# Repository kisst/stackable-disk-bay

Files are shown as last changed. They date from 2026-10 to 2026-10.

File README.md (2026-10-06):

# Stackable disk bay



A 3D-printable bay and toolless caddy for 3.5" hard drives, and for 2.5"
drives through an adapter in the same caddy. Bays are identical
and sit on top of and beside each other, located by hex bumps that drop into
the neighbour's honeycomb, with no connector parts. The drive drops into the
caddy without screws; the caddy slides into the bay and clicks home. Every
part prints flat, no supports.

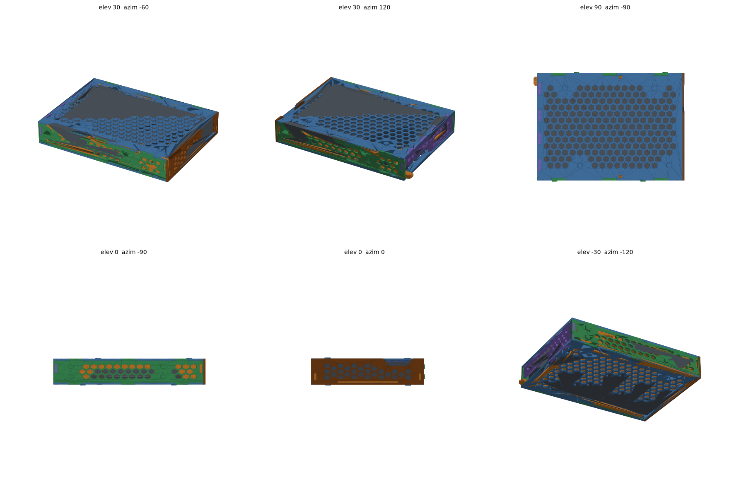
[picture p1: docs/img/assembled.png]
One assembled unit from six directions, one colour per printed part


**Status: first test print done; its findings are in this revision, which
is verified by the geometry checks but not yet reprinted.** The drive-in-caddy
fit is still untested. See [docs/design.md](docs/design.md) for the spec and
the print results.

## Parts

| Part | File | Per bay | Print |
| --- | --- | --- | --- |
| Caddy tray | `scad/caddy_tray.scad` | 1 | flat on its floor |
| Caddy bezel | `scad/bezel.scad` | 1 | flat, front face down |
| Plate, top and bottom | `scad/plate.scad` | 1 + 1 | flat, bumps up; top has six slots, bottom two |
| Wall (left and right) | `scad/wall.scad` | 2 | flat, bumps up |
| Rear panel | `scad/rear.scad` | 1 | flat |
| Pin coupon | `scad/coupon.scad` | optional | flat |

Accessories:

| Part | File | Use | Print |
| --- | --- | --- | --- |
| 2.5" adapter | `scad/adapter25.scad` | one per 2.5" drive, in a normal caddy | flat on its base |
| Foot | `scad/foot.scad` | four under each bottom bay | flat, pins up |
| Width joiner, 1 and 0.5 | `scad/joiner.scad`, `kind="w1"` / `"w05"` | between stacked bays | flat |
| Height joiner, 3, 1 and 0.5 | `scad/joiner.scad`, `kind="h3"` / `"h1"` / `"h05"` | between bays side by side | flat |

Print the coupon first: a 34 mm slice of the caddy with one fixed pin and one
finger, to check pin diameter and finger stiffness on a real drive.

Views (not prints), all in `out/` after a render:

| Image | Shows |
| --- | --- |
| `assembled.png` | one assembled unit, every printed part plus the drive |
| `testfit.png`, `testfit_open.png` | one unit with the drive and SATA plugs, one colour per part; the second with the top plate lifted off |
| `assembly_steps.png` | assembly drawing: walls on the rear panel's side tabs, lifted above the bottom plate, top plate above |
| `join_stack.png`, `join_side.png`, `join_detail*.png` | how bays join, exploded and close up |
| `assembly_parts.png` | the 2 × 2 combo, one colour per part class |
| `assembly_units.png` | the 2 × 2 combo, one colour per bay |

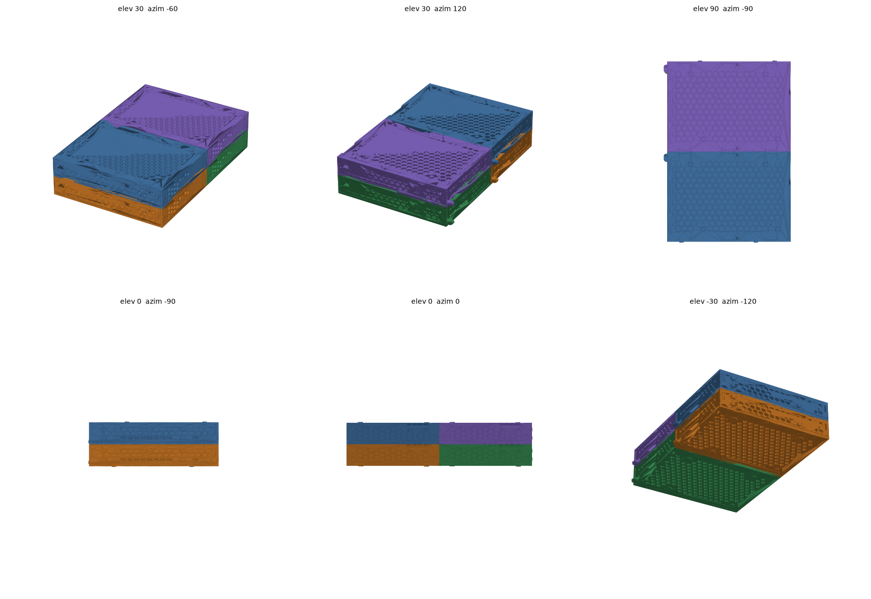
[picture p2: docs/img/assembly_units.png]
A 2 × 2 block of loaded bays, one colour per bay


The walls and rear panel carry a low groove that must line up round the
bay. The plates need no mark: the top has six slots, the bottom two, and
the rear-panel slots sit at the rear edge.
`scad/hdd.scad` is the reference drive and `scad/sata_plugs.scad` the mated
cable plugs used for the rear cutout check.

## Assembly

Step by step with pictures: [docs/assembly.md](docs/assembly.md).

## How it works

- **Drive in caddy.** Two fixed pins on one wall, two pins on 45° cantilever
  fingers on the other. Tilt the drive onto the fixed pins, press the other
  edge down, the fingers flex out and the pins snap into the drive's side
  holes. The fingers are diagonal so their slots print without support; the
  recessed tip gives a fingernail purchase to release.
- **Caddy assembly.** The bezel presses onto tabs on the tray's walls and
  floor, a friction fit; glue is optional.
- **Caddy in bay.** Slide it in until the bezel seats on the bay's front face.
  The top edge of each caddy wall is a leaf spring with a ramped bump. The
  bumps ride under the top plate's solid rim and drop into two slots when
  the caddy seats. The springs stay preloaded, holding the caddy down and the
  bezel tight against the bay. There is no honeycomb on the bump's track, so
  there are no false clicks. To remove, pull by the notch cut into the
  bezel's top edge; there is no handle, so the bezel prints flat. Or push it
  out from behind: the tray's rear corner reaches through the rear panel's
  open SATA corner as a push tab.
- **Bay assembly.** Walls slid onto the rear panel's side tabs; that U
  lowered into the bottom plate; top plate on. Every tab fits its slot
  exactly. The panel's open corner clears the SATA plugs. Glue is
  optional. A set of checks proves the insertion path.
- **Bay to bay.** No extra parts. Every bump stands on its part's honeycomb
  lattice, offset so that the same part turned for the opposite face presents
  an open cell where each bump arrives: plates turned over for stacking,
  walls turned end for end for side by side. Set a bay on top or beside,
  facing the same way, done. Bumps locate, they do not lock: glue them if a
  block must lift as one.
- **Airflow.** Honeycomb through plates, walls, caddy floor and bezel, inside
  solid rims that carry the load.

## Tooling

Needs Docker and a stock `python3` (standard library only). OpenSCAD
(`openscad/openscad:2021.01`) and the preview renderer run in containers.

```sh
scripts/render.sh          # STL + PNG for every part and view -> out/
scripts/assemblies.sh      # coloured 3MF assemblies -> out/assemblies/
scripts/check.sh           # all interference checks; all must PASS
scripts/check.sh quick     # single unit and neighbours only
scripts/check.sh array     # loaded 2x2 combo only (slow, CGAL)
scripts/check.sh acc       # accessories: 2.5" adapter, feet, joiners
scripts/check.sh only a b  # the named checks only
scripts/thin.sh            # no part has material under 0.8 mm (two perimeters)
AXES=z scripts/thin.sh wall  # one part along one axis
scripts/vent.sh            # caddy floor and bay plate honeycombs line up
```

`scripts/check.sh` intersects pairs of bodies and asserts the result is empty
(a face-to-face touch passes, a volume fails), or, for the hold checks, that a
displaced part hits material: tabs shifted in their slots, neighbours shifted
along the bay into the bumps. `scripts/thin.sh` slices every part in its print orientation,
opens each slice by 0.4 mm and fails on whatever the opening removed, unless
it is only the tail of a slice grazing a sharp corner.

GitHub Actions runs `check.sh`, `thin.sh` and `vent.sh` on every push and
pull request, and builds the printable STLs and the 3MF assemblies as
downloadable artifacts. Pushing a `v*` tag publishes both as a GitHub Release
once every check passes. The 3MFs carry one coloured object per part:

| 3MF | Contents |
| --- | --- |
| `assembled_hdd35.3mf` | bay, caddy and 3.5" drive, seated |
| `assembled_hdd25.3mf` | bay, caddy, 2.5" adapter and 2.5" drive, seated |
| `bay.3mf` | the bay alone: plates, walls, rear panel |
| `caddy_hdd35.3mf` | tray, bezel and 3.5" drive |
| `caddy_hdd25.3mf` | tray, bezel, 2.5" adapter and 2.5" drive |

## Layout

```text
scad/       params.scad lib.scad hdd.scad hdd25.scad sata_plugs.scad              shared model
            caddy.scad bay.scad accessories.scad
            caddy_tray.scad bezel.scad plate.scad wall.scad rear.scad coupon.scad  printable parts
            adapter25.scad foot.scad joiner.scad
            testfit.scad assembly.scad joining.scad steps.scad accessory_views.scad   views
            checks.scad thin.scad vent.scad                                        verification
scripts/    render.sh assemblies.sh check.sh thin.sh vent.sh
            preview.py color_mesh.py stl_components.py stl_bbox.py
docs/       design.md adr/ img/
out/        build output (ignored)
```

## License

[MIT](LICENSE)

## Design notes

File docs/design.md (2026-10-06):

# Design

## Goals

1. Hold a 3.5" drive (SFF-8301) without screws or tools, and a 2.5" drive
   (SFF-8201) through an adapter that takes the 3.5" drive's place in the
   same caddy, with no change to the caddy or bay.
2. Bays stack vertically and join side by side, with a positive clip-in
   connection; every bay is the same part.
3. Print on a common 220 × 220 mm bed, every part flat, no supports.
4. Keep air moving over and under the drive; stay rigid enough that a stack
   of loaded bays does not rack.

Non-goals for now: backplanes, fans, hot-swap electronics, and any metal
hardware.

## Coordinate frame

Shared by every part so the assembly and the checks need no offsets.

- **x** rear → front. The drive's connector face is at x = 0, the bezel at the
  front.
- **y** width, centred on 0. −y is the fixed-pin wall; +y is the finger
  wall and the side the drive's SATA connector is on (on the left, seen
  from behind with the label up).
- **z** 0 is the caddy floor's underside, which is also the bay floor's top.

## Drive envelope used

| | mm | source |
| --- | --- | --- |
| width | 101.6 | SFF-8301 A3 |
| length | 147.0 max | A4 |
| height | 26.1 max | A1 |
| side holes above bottom | 6.35 | A8 |
| side holes from connector face | 28.5 and 130.1 | A6, A6 + A7 |
| side hole thread | 6-32 UNC, minor ≈ 2.8 | |

The pins are 2.6 mm so they enter the thread's minor diameter with 0.1 mm a
side. Shorter or lower drives (20.2 mm) fit; only the hole positions matter.

## Caddy

A tray: honeycomb floor in a 6 mm solid frame, two 2.4 mm walls 25 mm tall
with honeycomb on the bay wall's lattice, and a front bezel the size of the
bay's face with a finger notch.

- **Fixed pins** on the −y wall at the two hole positions, conical tips.
- **Finger pins** on the +y wall sit at the lower ends of two cantilever
  fingers that run at 45° from the wall's top rim down to the pin, 6 mm wide
  in the wall's plane, 1.6 mm thick (the outer face is recessed 0.8 mm), cut
  free by a 1.2 mm slot. The angle is for printing: every slot face is a 45°
  overhang, so the tray prints flat with no support, where a horizontal
  finger floats over its lower slot on its first layer. The beam's lowest
  corner is cut flat 1.6 mm wide, so its first layer is a bead four lines
  wide rather than a point. The fingers are about 18 mm long; clearing the
  2.1 mm pin takes about 2.3 mm of deflection, which is about 1.5 % strain
  at the root: fine in PETG, acceptable in PLA. The recessed outer face
  gives a fingernail the purchase to release, but a test fit showed that
  is not enough once the pins are in a drive's holes.
- **Service holes**: one honeycomb cell on the wall lattice beside each
  finger's tip, at pin height (the lattice row at 8.25 mm), the first cell
  past the slot's tip corner: x 137.55 for the front finger, 20.55 for the
  rear. It overlaps the slot's end, so hole and slot are one opening, and
  a small screwdriver gets at the tip to pry the pin out of the drive. The
  cell's slanted edges run on to the slot's edges, so no step of wall is
  left where the two meet, and the wedge of wall above and below each
  meeting point is cut flat where it is 1 mm wide, so its first layers are
  not thinner than two perimeters. It
  clears the beam by 0.2 mm (front) and 0.7 mm (rear); `service_holes()`
  asserts that. The 3 mm rim above a finger
  is measured from the slot's highest point, the corner of its ring at the
  root, which sits 3 mm above the beam's centreline.
- **Spring lock** for retention in the bay, on the top edge of both walls.
  A 54 mm slit under the rim (x 56 to 110, between the +y wall's finger
  slots) frees a 2 mm beam anchored at both ends, under a 1.5 mm hump that
  rises from the rim on 15° ramps with 6 mm radii. A bump in the beam's
  middle rides on the top plate's underside. It has a 30° lead-in ramp facing
  the rear, a 45° holding ramp facing the front and a 1.2 mm crest, with
  1.5 mm fillets at its foot and a 1 mm radius on the crest, and reaches
  1.0 mm into the plate when relaxed. Its track
  lies under the plate's solid rim, outside the honeycomb, so it has nothing
  to drop into until it reaches its slot at the seated position. The slot's
  front edge meets the holding ramp with 0.4 mm of deflection left, so the
  spring keeps pushing the caddy down and the bezel onto the bay. Anchored at
  both ends, the beam's underside prints as a bridge; the bump stands upright
  on the edge. The beam rate is about 4 N/mm in PETG and 7 N/mm in PLA per
  side, at 0.8 % strain when pressed flat. A finger in the bezel's notch
  overcomes the 45° ramps.
- **Push tab** at the rear +y corner, so the caddy can be pushed out from
  behind without loading the bezel joint. The tray's floor corner runs back
  through the rear panel's open SATA corner and ends 5 mm behind the bay's
  rear face. It is a floor-level plate 10 mm wide, which passes under the
  SATA plugs (their housings start 2.4 mm up), plus a 6 mm rib in line with
  the side wall that sweeps up into the wall's rear edge on an 8 mm fillet.
  Both rear corners are rounded in plan and the rib's top edge is rounded.
  It prints on the bed with the tray.
- **Wall vents**: the caddy walls reach 27 mm and would otherwise cover
  the bay's side honeycomb, so they carry the same 6 mm lattice, phased to
  the bay wall's, with solid zones round fingers, pins and the bezel tabs.
  The zone round a finger is the bounding box of its slot ring and recess
  plus the 1.5 mm web margin, so no cell comes near a slot's tip corner.
- **Bezel** is a flat 2 mm plate the size of the bay's front face. It seats
  on the front edge of the plates and walls and carries a honeycomb intake
  over the drive's front. There is no handle. A drawer-style notch in the
  top edge near the +y corner, 36 mm wide, 14 mm deep, with rounded corners,
  gives a place to pull by; the honeycomb stays solid round it. It joins the
  tray by three tabs, one on each wall end and one on the floor, through
  slots in the plate. It is a separate print, front face down, because its
  lower edge reaches below the tray's floor.
- **Bezel lip**: a 2 mm lip on the bezel's back face at the top, 1.4 mm
  thick, 3.5 lattice pitches (27.3 mm) long, from y −26.1 to 1.2: the
  middle, where the top plate sags most, on the fixed-pin side and clear of
  the finger notch. When the caddy is seated it sits under the top plate's
  solid front rim, its top 0.2 mm under the plate's underside, and props the
  plate up. A 0.5 mm chamfer on its rear top edge lets a sagging plate ride
  up onto it. It reaches 1.5 mm over the drive's front edge, 0.3 mm above
  a 26.1 mm drive. The drive goes in fixed-pin edge first and sits lowest
  there, and passes under the lip by flexing the bezel as the other edge
  is pressed down. Checks: `bezel_lip_holds` (the plate let down 0.4 mm
  hits it) and `path_bezel_lip` (3 mm from seated, the lip is already
  under the rim and clears the bay).
- **Wall front posts**: near its edges the top plate is propped by the
  caddy walls instead. Over their last 8 mm at the bezel end both walls
  rise from 27 mm to 29.8 mm, 0.2 mm under the plate's underside, with a
  45° ramp behind that lifts a sagging plate as the caddy goes in. The
  0.2 mm gap, like the lip's, keeps them from binding in a bay printed a
  little short. Check: `posts_hold`.

Clearances: 0.3 mm a side drive-to-caddy, 0.4 mm a side caddy-to-bay.

## Bay

Five flat parts, all 2.4 mm: two identical plates, two identical walls and a
rear panel. Inner section 107.8 × 30.0; the bay runs from 5 mm behind the
drive's connector face to the bezel, 152.5 mm. The bezel stops the caddy.

- **Plate**: honeycomb inside a 6 mm rim, six through-slots for the wall
  tabs, rear-panel slots (four in the top plate, two in the bottom), two
  lock slots for the caddy's spring bumps in the top plate only, four hex
  bumps on one face. The bottom plate is turned over so its bumps face
  down.
- **Wall**: honeycomb inside a 4 mm rim, three 14 mm tabs on each long edge,
  four hex bumps on the outer face on the lattice's rows +1 and −1, and a
  slot for the rear panel's side tab, sized to the tab. The right wall is
  the same part turned end for end, so the slot is cut at both ends; the
  front one is unused, behind the bezel.
- **Rear panel**: an L. The lower +y corner is open from the bottom edge
  and the side edge up to 12.5 mm, just under the wall tab, for the SATA
  power and data plugs; a closed window there would leave slivers weaker
  than no material. Exhaust honeycomb over the rest, four tabs along the
  top edge into the top plate, two on the −y half of the bottom edge into
  the bottom plate, and one tab on each side edge, 13 to 25 mm up, through
  a slot in each wall. Each plate carries only the slots the
  panel's tabs use; the bottom plate's are mirrored, as it is turned over.
  The panel sits 1.2 mm behind the drive's connector face.
- **Front**: with the caddy in, its tray sits inside the bay at 0.4 mm a
  side, which keeps the walls from spreading; the bezel plate only seats on
  the front edge. The rear panel squares the back.
- **Orientation marks**: a 1 mm groove, 0.6 mm deep, runs along the outside
  of both walls and the rear panel 1.8 mm above the inner floor. When the
  three grooves line up in one low line round the bay, every part is the
  right way up; a wall or panel put in upside down shows its groove near the
  top. The plates need no mark. Their rear-panel slots sit at the rear
  edge, which shows which way round a plate goes, and the bumps face out.
  Top and bottom are separate prints told apart by their slots: the top
  plate has six (four for the rear panel, two for the caddy lock), the
  bottom plate two (the rear panel's, mirrored because it is turned
  over). The wall has a rear-panel slot at both ends so one part serves
  both sides without a mirror image; the unused front slot sits behind the
  bezel.
- **Fit**: wall tabs are 0.15 mm a side smaller than their plate slots. The
  rear panel's tabs are 0.08 mm a side in every slot, a friction fit. Press
  together; a drop of glue at the tabs makes it permanent.

### Joining bays

No extra parts in either direction. Every bump is 5.6 mm across flats,
1.4 mm tall, and stands on its part's own 6 mm honeycomb lattice, placed so
that when the identical part is turned for the opposite face, each bump of
one bay arrives in an open cell of the neighbour's part.

**Stacking.** The plate bumps sit at columns −6 and +6 of row +6 and
columns −4 and +8 of row −6. Turning the plate over for the bottom mirrors
y, so each bump lands two cells from any pad: an open cell. Stack pitch is
the bay height, 34.8 mm. The offset depends on both bays facing the same
way, front to front.

**Side by side.** The walls share the 6 mm lattice (three rows fit in the
30 mm height; the bumps use rows +1 and −1 and leave row 0 for venting).
The right wall is the left wall turned end for end, which maps column i to
−i−1 on those rows. Bumps at columns −8 and +4 land at +7 and −5, three
cells from any pad. Bays touch; lateral pitch is the bay width, 112.6 mm,
and neighbouring bezels meet edge to edge.

Both joints locate and square the array and stop sliding; neither carries
a bay if its neighbour is lifted. Glue the bumps for that.

To join, set the next bay on top, or bring it in from the right, facing the
same way; its cells drop over the bumps and the faces
touch. The array grows as high and as wide as you like.

### Assembling a bay

Insertion order and directions; [assembly.md](assembly.md) has the same steps
with pictures:

1. **Walls onto the rear panel.** Panel groove low, SATA notch at the
   bottom on the +y side, the drive's connector side. Slide each wall
   sideways onto the panel's side tab, wall groove low on the outside;
   either end of a wall may face the rear. Panel and walls now stand as a
   U.
2. **Into the bottom plate.** The plate with two slots, bumps down, slots
   at the rear. Lower the U onto it: the walls' three bottom tabs and the
   panel's two bottom tabs all drop into their slots together.
3. **Top plate on.** The one with six slots, bumps up, the row of four at
   the rear; it drops over the walls' top tabs and the panel's four top
   tabs. Glue the tabs if the bay will be moved about.

Because the walls go onto the panel before either meets a plate, every
slot only ever sees one direction of travel and fits its tab exactly; the
v0.1.0 order, panel in the plate first and walls slid on lifted, needed a
side slot 2.4 mm too tall. `scripts/check.sh` proves the path: a wall
approaching the panel sideways, the U half-way down into the bottom plate,
and the top plate half-way down all clear the parts already placed. A
panel shifted 1 mm along the bay hits the walls alone, so the side tabs
really sit in the slots.

### Venting

Honeycomb (6 mm cells, 1.8 mm web) through both plates, both walls and the
rear panel, stopping 6 mm from the plate edges and 4 mm from the wall edges.
The walls fit three rows; the bumps take rows +1 and −1 and row 0 vents.
Cells are skipped within 1.5 mm of a bump, a tab slot, a lock slot or the
SATA cutout. Air enters through the
bezel, passes over and under the drive, and leaves through the rear panel.

The caddy floor and the bay's bottom plate are two honeycombs in series
under the drive. They use the same 6 mm lattice and the caddy's grid is
phased to the plate's centre, so the cells coincide when the caddy is in.
`scripts/vent.sh` sections both at mid-thickness and intersects them:

| | open area | of drive footprint |
| --- | --- | --- |
| caddy floor alone | 6955 mm² | 46.6 % |
| bay bottom plate alone | 6485 mm² | 43.4 % |
| straight through both | 6105 mm² | 40.9 % |

The remaining loss is the plate's solid pads around bumps and tab slots,
which the floor cannot see past. The script fails if
the through-open area drops under 85 % of the smaller layer, which is what
a drift between the two lattices would look like. The open floor lets air
reach the drive's underside, where the PCB and spindle motor are. The
bezel uses the same 6 mm cells as every other part.

## Accessories

### 2.5" adapter

The adapter takes the place of a 3.5" drive in an ordinary caddy, so the
caddy, bay and rear panel are unchanged. It is 101.6 mm wide with holes for
the caddy's four pins: teardrop holes through a strip along the +y wall for
the finger pins, and through an outer rail on the −y side for the fixed
pins.

SATA puts the connector at the same place on both sizes: SFF-8323 (3.5")
and SFF-8223 (2.5") both give 13.43 mm from the drive's edge to the blade
and 3.5 mm up from the bottom. So the 2.5" drive sits in the adapter's +y
rear corner, on the caddy floor with its connector face at x = 0. Its
connector then lands where a 3.5" drive's would, moved inboard only by the
2.2 mm strip that carries the finger pins plus 0.2 mm clearance. The plugs
still pass through the rear panel's open corner.

The 2.5" drive hangs on three pins into its M3 side holes (SFF-8201: 3 mm
up, 14.0 and 90.6 mm from the connector end): two on the −y rail, one on
the +y strip near its free end. Tilt the drive onto the rail's pins and
press the other side down; the strip flexes out and its pin snaps in. In
the caddy the strip is backed by the caddy wall, so the drive cannot come
out; at the strip's pin, 14 mm from the rear, that wall is solid, ahead of
the first finger's slot. The base beside and in front of the drive
carries honeycomb on the caddy floor's lattice. Drives 5 to 15 mm tall fit.

### Feet

A hexagonal foot, 24 mm across flats, lifts the bottom bay 12 mm for air
under it. Three hex pins, the bumps' shape and 2.0 mm tall, drop into three
neighbouring open cells of the bottom plate, two in one row and one in the
row above between them. The pins stay inside the 2.4 mm plate, clear of
the caddy floor. Four feet go near the corners, at the cell clusters in
`foot_cells`; any cluster of three open cells works.

### Joiner plates

A joiner is sandwiched between two bays: bay, joiner, bay. It is 2.8 mm
thick, twice a bump's height, so each bay's bumps drop 1.4 mm into holes
from its own side. Width joiners go between stacked bays and come one or
half a bay wide. Height joiners go between bays side by side and come
three, one or half a bay high. All are as long as the bay.

Pieces lock edge to edge with dovetails, two tabs and two sockets per
edge. The sockets sit at the mirror positions of the tabs, so a piece
turned round still mates. Half pieces lock on one edge only, so they end a
run flush. 0.5 + 1 + 0.5 lays a joint two bays long whose seams fall at
mid-bay, tying the two bays together like bricks; 0.5 + 0.5 covers a single
bay.

The plates are honeycomb all over, on the lattice of the bay half each
zone lies against, so every bump lands in a cell and air passes straight
through. The lattice is symmetric about a bay's centre line, so a half
piece cut for the half on one side of it serves the other half turned
round. A full piece straddles the seam between two bays, as in a run; a
single bay takes two half pieces. The three-high piece runs from one bay's
centre line to the one three bays up, so 0.5 + 3 + 0.5 joins four rows.
Width zones fit seven rows of cells. Height zones, 17.4 mm high, fit only
the bump row, with cells skipped next to the dovetails.

Columns of a block with width joiners touch directly, and so do the rows
of a block with height joiners. Use one joiner direction per block: either
direction already ties the block together. Stacked pitch with a joiner is
37.6 mm, side-by-side pitch 115.4 mm.

## Print orientation

Everything flat, nothing needs support.

| Part | Footprint | Notes |
| --- | --- | --- |
| Caddy tray | 107 × 159.5 mm, 31 mm tall | pins are small horizontal protrusions; finger slots are 45°; the spring slits bridge 54 mm |
| Caddy bezel | 112.6 × 34.8 mm, 4 mm tall | front face down; a flat plate with the 2 mm lip standing up |
| Plate, top and bottom | 112.6 × 152.5 mm | bumps up; slots differ |
| Wall | 152.5 × 34.8 mm | bumps up |
| Rear panel | 112.6 × 34.8 mm | |
| Coupon | 34 × 107 mm | |
| 2.5" adapter | 143.5 × 101.6 mm, 12 mm tall | caddy-pin holes are teardrops; the drive pins are small horizontal protrusions |
| Foot | 24 mm across flats, 14 mm tall | pins up |
| Width joiner | 152.5 × 112.6 (1) or 56.3 mm (0.5), 2.8 mm | |
| Height joiner | 152.5 × 104.4 (3), 34.8 (1) or 17.4 mm (0.5), 2.8 mm | |

## Verification

`scripts/check.sh` proves, by boolean intersection in OpenSCAD:

- the walls' and rear panel's tabs sit in their slots without overlap, and a
  wall or panel shifted 1 mm hits plate or wall material (the tabs engage);
- the rear panel clears the drive and its connectors, and the bezel seats on
  the bay's front face (a bay pushed 1 mm forward hits it);
- the caddy with a drive sits inside the bay touching only where the bezel
  seats and where the preloaded lock bumps bear on their slots' front edges;
  the drive touches the caddy only on the floor (pins are inside the holes);
- the push tab clears the mated SATA plugs, and every part of the tray that
  ends up behind the rear panel passes through the panel's open corner on
  the way in;
- the seated caddy pulled 1 mm out hits the lock slots; while sliding in,
  with the bumps pressed flat, it clears the bay; the bumps' track from the
  bay's front edge to the slot is solid plate;
- stacked and side-by-side neighbours touch only on their faces, and a
  neighbour shifted 1 mm along the bay hits the bumps (they sit in open
  cells of the neighbour's part);
- in a 2 × 2 array with a caddy and drive in every bay, no loaded unit
  overlaps any other, including the diagonals, and a loaded caddy never
  reaches a neighbour's bumps;
- accessories (`check.sh acc`): the 2.5" adapter sits in the caddy and the
  2.5" drive in the adapter, its plugs pass the rear panel, and each is held
  by the pins; the feet sit in the bottom plate's cells and hold; width and
  height joiners sit between their bays, a 0.5 + 1 + 0.5 run fits both
  ways, its dovetails lock, and a joiner shifted 1 mm hits the bumps.

`scripts/thin.sh` proves that no printed part has material thinner than two
perimeters (0.8 mm). It slices each part in its print orientation every
0.4 mm along z and every 2 mm along x and y, opens each slice by 0.4 mm
(straight-edged erosion, round dilation, so a tapering wedge is caught as
well as a parallel sliver) and exports what the opening removed. The round
dilation also nibbles every convex corner by 0.4 mm: a right-angle nib is
0.034 mm², two of them merged across a hair-thin slit about 0.07 mm², so
anything under 0.1 mm² is dropped; a real thin wedge, such as one over a
finger root, is 0.3 mm² or more. What remains is classified by how
it joins the thick material: at two or more places it is a neck or a roof
and fails; over more than 1.5 mm it is a fin and fails; at none it is an
island, which fails in the z pass (a first layer in the air, or a pillar)
and passes in the x and y passes, where an island is the apex of a corner
pointing along the slice normal and anything real there is a neck or fin
in another pass; a single short contact is the tail a slice leaves when it
grazes a sharp corner, and passes. Pins are left off the tray for this
check: a horizontal cylinder sliced near its tangent is
always thin.

The reference drives (`scad/hdd.scad`, `scad/hdd25.scad`) carry a SATA
device plug to the SATA-IO layout, horizontal L-shaped tongue at the bottom
of the connector face, 7-contact signal segment nearest the drive's edge,
15-contact power segment inboard, 1.27 mm pitch, in a pocket. A separate
model, `scad/sata_plugs.scad`, holds the mated data and power cable plugs,
and a check proves they pass through the rear panel's cutout. The
connector's position is from SFF-8323: the blade starts 13.43 mm from the
drive's edge (dimension A13) and sits 3.5 mm up from the bottom (A7).
SFF-8223 gives the same two numbers for 2.5" drives. The edge is the +y one:
seen from behind with the label up, the connector is at the left, data plug
outermost. A real drive shows this; the first model had it mirrored ([ADR
0010](adr/0010-sata-connector-on-the-plus-y-side.md)). Segment lengths and
pocket depth are nominal, so the cutout should still be confirmed against a
real drive before printing many rear panels.

## First print

The first test print found:

1. The rear panel was loose in the walls: the side tab sat in a slot 2.4 mm
   taller than itself, slack the old lifted-wall assembly needed. Now the
   walls go onto the panel first and the slot fits the tab exactly.
2. The caddy never clicked into the bay: the detent bumps on the side finger
   barely reached past the slide clearance and the finger yielded inward.
   Now a leaf spring on each wall's top edge locks into the top plate.
3. The bezel tab slots, the long floor slot above all, were too loose to
   hold without glue. Now 0.08 mm a side across the wall tabs and 0.05 mm
   across the floor tab.
4. The rear panel's plate slots were too loose. Now 0.08 mm a side.

See [ADR 0005](adr/0005-top-edge-spring-lock-grooved-rear-panel.md).

After the print, the bezel's handle was replaced by a finger notch, so it
prints as a flat plate; see
[ADR 0006](adr/0006-bezel-finger-notch-instead-of-handle.md).

## What the next print has to answer

1. Whether the tighter friction fits (bezel tabs, rear panel) press home by
   hand and hold without glue.
2. Spring lock: click, hold and release force, and whether the 54 mm slit
   bridges cleanly in the chosen filament.
3. Whether the bezel notch gives enough grip to pull the caddy out against
   the spring lock.
4. Drive in caddy, still untested: finger stiffness at 1.5 % strain, and
   whether 2.6 mm pins seat in the tapped holes of the drives on hand.
5. Fit of the 5.6 mm bumps in the 6.0 mm cells; one parameter.
6. Rigidity of a loaded 2 × 2 block located by bumps alone; if it racks,
   glue the bumps.
7. Whether a drive goes into a caddy with its bezel on, under the bezel's
   lip, by flexing the bezel, and whether the lip holds the top plate up.
8. The rear panel's open corner on the +y side against the real drive's
   plugs ([ADR 0010](adr/0010-sata-connector-on-the-plus-y-side.md)).

## Open questions

- None at the moment.

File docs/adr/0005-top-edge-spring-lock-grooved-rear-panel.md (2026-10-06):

# 0005 — Top-edge spring lock, grooved rear panel, tighter press fits

> **Partly superseded by [0009](0009-rear-panel-side-tabs-walls-first.md)**:
> the rear panel's grooves gave way to side tabs again, with the walls going
> onto the panel first. The spring lock and the clearances stand.

## Context

The first test print found four problems.

1. The rear panel was loose in the walls. Its side tab sat in a slot 2.4 mm
   taller than the tab, because the lifted-wall assembly path of 0004 needed
   that slack.
2. The caddy never clicked in. The detent bumps sat on a 45° finger whose
   outer face was recessed 0.8 mm. Only about 0.6 mm reached past the 0.4 mm
   slide clearance, and the thin finger just yielded inward. The bumps were
   also horizontal spheres on a vertical face, which print poorly.
3. The bezel tab slots, the long floor slot most of all, were too loose to
   hold without glue.
4. The rear panel's plate slots were too loose for a friction fit.

## Decision

- **Spring lock on the top edge** (proposed by the printer's owner). Each caddy
  wall has a 54 mm slit under its top rim. That frees a 2 mm beam anchored at
  both ends, under a 1.5 mm hump. A bump in the beam's middle has a 30°
  lead-in ramp at the rear, a 45° holding ramp at the front and a 1.2 mm
  crest. It rises 1.0 mm above the top plate's underside when relaxed. The
  bump runs under the plate's solid rim, outside the honeycomb, and drops
  into a slot when the caddy seats. The slot's front edge is placed so the
  holding ramp bears on it with 0.4 mm of deflection left. The spring then
  pushes the caddy down and the bezel onto the bay, so the caddy is tight as
  well as locked.
- The beam is anchored at both ends, not a cantilever. Its underside then
  prints as a bridge between two anchors; a cantilever's underside would be
  a 54 mm line extruded into air from its root. The fixed-fixed beam is also
  64 times stiffer for its length. That is why a 2 mm beam gives a useful
  preload at under 1 % strain.
- The bump prints upright on the wall's top edge, so nothing horizontal is
  left on the outside of the tray. The side detent finger and the bay wall's
  detent holes are gone.
- **Rear panel in grooves.** The walls carry a 1.2 mm deep groove on their
  inner face, open at the top edge. The panel's side edges are tongues from
  13 mm up to the top. The walls drop into the bottom plate first, then the
  panel drops in from above, then the top plate goes on. The tongue fills its
  groove with no slack, and the top plate caps it. A through-slot open at the
  top would have left a 1.3 mm prong at the wall's end; a blind groove keeps
  the wall whole.
- **Clearances.** Panel tabs in plate slots and tongues in grooves are 0.08 mm
  a side. Bezel wall tabs are 0.08 mm across their thickness, and the floor
  tab is 0.05 mm. Along a tab's length the clearance stays 0.15 mm, which
  grips nothing and leaves room for elephant foot. Wall tabs in plates keep
  0.15 mm, since the print showed no problem there.

## Consequences

- Assembly is simpler: no lifting and sliding.
- The plates carry only the two rear-panel slots each one uses: the top and
  bottom prints mirror each other, dropping 0004's two unused slots.
- Each plate has two lock slots, 3.1 × 3.4 mm, one per side. The bottom
  plate's pair is unused.
- The pin coupon shrinks to 34 mm so it stops short of the spring slit.
- Checks: the seated caddy pulled 1 mm out hits the slots (`caddy_locked`).
  The sliding caddy with the bumps pressed flat clears the bay
  (`path_caddy_slide`). The bump track from the front edge to the slot is
  solid plate (`lock_track`). The panel shifted 1 mm along the bay hits the
  walls alone (`rear_in_grooves`). The new insertion path is swept.
- The spring rate depends on the filament. At 2 mm beam depth it is about
  4 N/mm in PETG and 7 N/mm in PLA, per side. `sp_h`, `sp_lock` and
  `sp_preload` tune it. The friction clearances are a second guess at the
  printer's tolerance, worth one more print.

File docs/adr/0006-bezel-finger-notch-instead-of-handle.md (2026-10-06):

# 0006 — Bezel finger notch instead of a handle

## Context

The bezel's grab bar stood 6 mm proud on two posts. Printed as a flat
plate, the bar is either a bridge over the posts or the plate floats on
them, so the part needed support. The handle exists only to pull the caddy
out.

## Decision

- No handle. The bezel is a flat 2 mm plate with a drawer-style notch in its
  top edge near the +y corner, as proposed by the printer's owner. The notch
  is 36 mm wide at the edge and 20 mm at the bottom, 14 mm deep, with 4 mm
  radii in the bottom corners and the mouth eased into the edge.
- The honeycomb intake stays solid round the notch.

## Consequences

- The bezel prints front face down, a plain plate: no bridge, no support,
  less material and time.
- The notch is the only grip. Whether it holds well enough against the
  spring lock is for the next print; the lock's release force is set by
  `sp_hold`, `sp_lock` and `sp_preload`.
- The thin check now places the bezel on the bed. Its old bounds missed the
  part entirely, so its layer slices had been testing nothing.

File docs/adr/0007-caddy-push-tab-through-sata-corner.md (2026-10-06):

# 0007 — Push tab through the rear panel's SATA corner

> **Mirrored by [0010](0010-sata-connector-on-the-plus-y-side.md):** the
> push tab is on the tray's rear +y corner, following the open corner.
> Otherwise unchanged.

## Context

The caddy comes out by pulling on the bezel, which loads the bezel's tab
joint, a friction fit. If the joint is loose or the notch grip is not
enough, there was no other way to get the caddy out.

## Decision

- The tray's rear −y corner reaches back through the rear panel's open SATA
  corner and ends 5 mm behind the bay's rear face, as a tab to push the
  caddy out from behind.
- It is a floor-level plate, 10 mm wide and 2 mm thick, which passes under
  the SATA plugs, whose housings start 2.4 mm above the floor's underside.
  A 6 mm rib in line with the side wall stiffens it. The rib sweeps up into
  the wall's rear edge on an 8 mm fillet. Both rear corners are rounded in
  plan, and so is the rib's top edge.

## Consequences

- The tray grows 13 mm toward the rear, to 159.5 mm overall, still on a
  220 mm bed and still printing flat with no support.
- The tab sits beside the plugs, so cables must leave room for a finger at
  that corner.
- Checks: the tab clears the mated plugs (`plugs_vs_caddy`). Everything on
  the tray that ends up behind the panel passes through its open corner on
  the way in (`path_caddy_past_panel`).

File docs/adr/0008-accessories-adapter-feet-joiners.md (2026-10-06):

# 0008 — Accessories: 2.5" adapter, feet, joiner plates

> **Mirrored by [0010](0010-sata-connector-on-the-plus-y-side.md):** the
> 2.5" drive sits in the +y rear corner. The flexible strip is on +y and
> carries the finger pins; the rail is on −y and carries the fixed ones.

## Context

Three additions were asked for: a 2.5" variant that keeps the SATA
connector where a 3.5" drive has it; feet that lift the bottom bay for
air and join by the hex system; and joiner plates, sandwiched between
bays, in one and half sizes that interlock so 0.5 + 1 + 0.5 makes a joint
two bays long.

2.5" drives had been a non-goal in `docs/design.md`; this decision lifts
that, and the goals now name them.

## Decision

- **2.5" as an adapter**, not a second caddy or bay. It replaces a 3.5"
  drive in the caddy and takes the caddy's four pins. SFF-8323 and SFF-8223
  put the SATA connector 13.43 mm from the drive's edge and 3.5 mm up on
  both sizes. So the 2.5" drive sits in the −y rear corner on the caddy
  floor, and its connector matches the 3.5" position. The only offset is
  2.4 mm inboard: the strip that carries the fixed pins plus clearance. The
  2.5" drive hangs on three pins, two fixed on the +y rail and one on the
  flexible −y strip, which the caddy wall then backs.
- The 3.5" reference model's connector moves from a guessed 6.4 mm to the
  standard's 13.43 mm. Only the checks use it; the rear panel's open corner
  already covered both.
- **Feet** lock into three neighbouring open cells with three bump-shaped
  pins. That holds better than one bump in a socket, and a foot can go
  under any cluster of open cells.
- **Joiners** are 2.8 mm thick, twice the bump height, and honeycomb all
  over on the lattice of the bay half each zone lies against, so the bumps
  find cells and air passes. They lock with genderless dovetails: sockets
  at the mirror positions of the tabs, so pieces turn round freely. Half
  pieces lock on their centre-line edge only and end a run flush; turned
  round they serve the other half of a bay. A full piece straddles the seam
  between two bays, and two half pieces cover a single bay. A three-high
  height piece spans from one bay's centre line to the one three bays up.

## Consequences

- No change to caddy, bay or rear panel for 2.5" drives; mixed sizes share
  a stack.
- A joiner adds 2.8 mm to the pitch: 37.6 mm stacked, 115.4 mm side by
  side. Neighbouring bezels no longer meet edge to edge.
- One joiner direction per block: the joined direction's bays touch
  directly, the other is spaced 2.8 mm by the joiners.
- New checks (`check.sh acc`): fit, hold and lock for every accessory.

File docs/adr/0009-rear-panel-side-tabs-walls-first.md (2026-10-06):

# 0009 — Rear panel side tabs back; walls onto the panel first

## Context

ADR 0005 replaced the rear panel's side tabs with tongues in blind grooves
on the walls' inner faces, so the panel could drop in last with no slack.
From the outside the panel then showed no join to the walls at all, which
the owner did not want: the side tabs of v0.1.0 should stay, with only the
loose slot fixed. v0.1.0's slot was loose because the panel went into the
bottom plate first and each wall was slid onto its tab while lifted one
plate thickness, so the slot had to be 2.4 mm taller than the tab.

## Decision

- The panel has a tab on each side edge again, 12 mm long at 13 to 25 mm,
  through a slot in each wall, as in v0.1.0. The slot fits the tab at
  0.08 mm a side, like the panel's other slots. The grooves are gone.
- New assembly order: slide the walls sideways onto the panel's side tabs,
  with no plate yet; lower that U into the bottom plate, where all five
  bottom tabs drop in together; then the top plate. Each slot sees one
  direction of travel only, so none needs extra length.

## Consequences

- The panel joins every neighbour by tabs: four into the top plate, two
  into the bottom plate, one into each wall.
- The U is loose at the front until it is in the bottom plate; hold the
  walls while lowering it.
- Checks: a wall approaching the panel sideways, the U half-way down into
  the bottom plate, and the top plate half-way down clear everything; the
  panel shifted 1 mm hits the walls alone (`rear_in_walls`).

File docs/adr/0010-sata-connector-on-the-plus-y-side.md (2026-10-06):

# 0010 — SATA connector on the +y side

## Context

The reference drive put the SATA connector at the −y edge: on the right,
seen from behind with the label up. SFF-8323 and SFF-8223 give the
connector's distance from "the drive's edge" (13.43 mm) but the model
guessed which edge. A real drive showed the connector on the other side,
at the left. Everything built around the connector was mirrored: the
rear panel's open corner would have been on the wrong side and the plugs
would have hit the panel.

## Decision

- The connector sits at the +y edge, 13.43 mm in; its segments run toward
  −y, data plug outermost. `sata_y0` is +37.37. The drive models draw the
  tongue and its pocket in a frame mirrored onto that edge
  (`at_connector()` in `scad/hdd.scad`); the cable plugs follow.
- Everything that follows the connector is mirrored with it, about y = 0:
  - the rear panel's open corner is now the lower +y corner, and its two
    bottom tabs sit on the −y half (−40 and −12 mm);
  - so the bottom plate's two rear-panel slots move to the other side.
    The top plate's four slots are symmetric and unchanged;
  - the caddy's push tab is at the tray's rear +y corner;
  - the 2.5" adapter: the drive sits in the +y rear corner, the flexible
    strip on +y carries the finger pins, the rail on −y the fixed ones.
- The fixed pins stay on −y and the fingers on +y. The connector does not
  care which wall flexes, and moving the fingers would touch every part of
  the caddy for nothing.

## Consequences

- Rear panel, bottom plate, caddy tray and adapter must be reprinted;
  top plate, walls, bezel, feet and joiners are unchanged.
- The adapter's strip now sits against the finger wall. Its pin, 14 mm
  from the rear, is backed by solid wall ahead of the first finger's slot,
  and the finger pins go through the strip as they went through the rail.
  The adapter goes in rail side first onto the fixed pins, strip side
  pressed down past the fingers.
- Seen from behind, the open corner, the plugs and the push tab are all at
  the bottom left.

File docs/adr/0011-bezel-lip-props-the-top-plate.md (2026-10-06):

# 0011 — A lip on the bezel props the top plate

## Context

The top plate is held along its side edges by the wall tabs. Its front
edge spans the 108 mm between the walls with nothing under it, and can be
pushed down there. The bezel already sits against that edge when the
caddy is seated.

## Decision

- A lip on the bezel's back face, at the top: 2 mm deep, 1.4 mm thick,
  3.5 lattice pitches (27.3 mm) long, from y −26.1 to 1.2. That is the
  middle, where the plate sags most; it sits on the fixed-pin side and
  clear of the finger notch. Seated, it sits under the top plate's solid
  front rim, its top 0.2 mm under the plate's underside. A first
  version ran 54.6 mm out to the −y wall; near the wall it did little, so
  it was halved to the middle.
- A 0.5 mm chamfer on its rear top edge, so a plate that has sagged rides
  up onto it as the caddy goes home.
- Kept minimal, and on the fixed-pin side. It reaches 1.5 mm over the
  drive's front edge with 0.3 mm above a 26.1 mm drive. The drive goes in
  fixed-pin edge first, already low under the lip, and the bezel flexes
  as the other edge is pressed down.
- Near the edges the caddy walls prop the plate. Over their last 8 mm at
  the bezel end they rise from 27 mm to 29.8 mm, 0.2 mm under the plate's
  underside, with a 45° ramp behind.
- Lip and posts stop 0.2 mm under the plate rather than flush. A plate
  sagging that far rests on them; a bay printed a little short does not
  make them bind before the lock bump reaches its slot.

## Consequences

- The bezel print stands 4 mm tall: the plate and the lip standing up
  from its back face. Still no support.
- The drive's way into a caddy with its bezel on is no longer free. It
  relies on the 0.5 mm front gap and on the bezel flexing. No check covers
  that path; it is a question for the next print.
- Between the lip and the +y wall post, by the finger notch, the plate's
  front edge is still unsupported for about 50 mm.
- The posts sit at the caddy's front end, so they only reach the bay over
  the last 11 mm of travel (ramp and flat), where they slide under the plate
  with 0.2 mm to spare.
- Checks: `bezel_lip_holds`, `posts_hold`, `path_bezel_lip`.

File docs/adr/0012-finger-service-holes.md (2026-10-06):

# 0012 — Service holes at the finger tips

## Context

On a test fit, a drive whose pins had engaged was almost impossible to
take out of the caddy. The fingers' recessed outer faces give a fingernail
too little to pull on against the pin's grip in the hole.

## Decision

- A honeycomb cell through the finger wall beside each finger's tip, on
  the wall's own lattice so it reads as part of the vent pattern. It sits
  on the lattice row at pin height (8.25 mm against 8.35 mm), and is the
  first cell past the slot's mitred tip corner: x 137.55 for the front
  finger, 20.55 for the rear one.
- The cell overlaps the end of the slot, so the hole and the slot are one
  opening and a screwdriver reaches the finger's tip. It does not touch
  the beam: 0.2 mm clear at the front finger, 0.7 mm at the rear one, and
  `service_holes()` asserts a clearance so a parameter change cannot cut
  into a finger.

## Consequences

- To remove a drive: pry each finger tip out through its hole, then lift.
- Where the cell's flat side meets the slot's 45° edges it would leave a
  small step of wall above and below; the cell's slanted edges are carried
  on to the slot edges instead, so the opening is clean. The wedges of
  wall left above and below each meeting point are cut flat where they
  are 1 mm wide: the thin-section check caught their tips printing as
  layers under 0.8 mm.
- Two more openings in the finger wall, both on the lattice, and no
  slivers where they meet their slots.
- The front hole reaches to 7 mm from the wall's front end, inside the
  zone otherwise kept solid round the bezel's wall tab.

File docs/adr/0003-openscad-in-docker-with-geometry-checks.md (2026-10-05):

# 0003 — OpenSCAD in Docker, with boolean interference checks as the test suite

## Context

Nothing beyond Docker should be needed on the host to build or verify the
model. The design has several mating interfaces whose fit is easy to
get wrong by a tenth of a millimetre and hard to see in a render.

## Decision

- Model in OpenSCAD, all dimensions in one `params.scad`, one shared
  coordinate frame for every part.
- Run OpenSCAD from the official image via `scripts/render.sh`. The image
  has no working offscreen GL, so previews are shaded from the STL by a
  small matplotlib script in a throwaway python container.
- Treat fit as testable: `scad/checks.scad` exports the intersection of
  pairs of bodies and `scripts/check.sh` asserts empty (or held, for the
  capture checks). OpenSCAD writes no file for an empty result and exits 1,
  so the script clears old outputs first and reads "no file" as "no overlap"
  only when the log says the result was empty and holds no error.
- A zero-thickness intersection (two faces touching) is a pass; only a
  volume fails.

## Consequences

- Any change to a mating dimension is caught before a print.
- Renders take ~30 s per part in CGAL; the full check suite runs in CI on
  every push.

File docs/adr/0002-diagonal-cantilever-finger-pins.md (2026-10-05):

# 0002 — Drive is held by pins on 45° cantilever fingers

## Context

The drive must drop into the caddy with no screws. Pins in the SFF-8301 side
holes are the natural toolless interface; something has to move about 2 mm
to let the second pair of pins in. The tray must print flat with no support.

## Options

1. Flex the whole +y wall outward (thin wall, anchored only at the floor).
2. Vertical tabs rooted at the floor carrying the pins.
3. Horizontal cantilever fingers cut into the wall, pin at the free end.
4. Cantilever fingers hanging at 45° from the wall's top rim.

## Decision

Option 4. Option 1 makes the wall too soft to guide the caddy, and a short
vertical tab (option 2) is strained past PLA's yield. A horizontal finger
(option 3) has two horizontal slot faces: printed flat, its first layer
floats over the lower slot, a 40 mm unsupported span inside a 1.2 mm gap
where support can be neither placed nor removed. Only a slot that climbs
along its length at 45° or more prints clean.

- Fingers hang from the wall's top rim at 45° down to the pin, 6 mm wide,
  1.6 mm thick (outer face recessed), 1.2 mm slots. Every slot face is a 45°
  overhang. The detent finger is the same shape.
- The wall is 25 mm above the floor to give the finger about 18 mm of
  length; pin engagement is 1.8 mm, so the deflection is about 2.3 mm and
  root strain about 1.5 %. Conical pin tips cam the fingers open as the
  drive is pressed down.
- The rim above a finger is measured from the slot ring's root corner, 3 mm
  above the beam's centreline, and the beam's lowest corner is cut flat
  1.6 mm wide, so no slice of the wall is thinner than two perimeters.
- The wall carries the bay wall's 6 mm honeycomb, phased to it, so the side
  vents stay open.

## Consequences

- No support anywhere in the caddy tray; the recessed outer face gives a
  fingernail purchase to release.
- The +y wall is weaker than the −y wall; the bezel and floor frame provide
  the tray's stiffness.
- The drive is retained by pin engagement, not clamping, as in metal
  caddies.
- 1.5 % strain is comfortable in PETG and acceptable in PLA, worth
  confirming with the coupon.

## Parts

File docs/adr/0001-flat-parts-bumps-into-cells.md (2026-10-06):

# 0001 — Bay is five flat parts; bays join by bumps in the neighbour's honeycomb

## Context

Bays must sit on top of and beside each other, every bay identical, every
part printed flat with no supports, and come apart again by hand. A stack
only has to stay put: the loads are shear (stop a bay sliding off) and a
little tension. Anything stronger can be had by gluing.

## Decision

- The bay is two identical plates, two identical walls and a rear panel,
  each printed flat with no supports, pressed together with tabs through
  slots. The rear panel squares the back; the caddy's tray inside the bay
  holds the front.
- Plates and walls carry a 6 mm honeycomb, and a hex bump is the same shape
  as a cell. Every outer face carries four bumps, 5.6 mm across flats and
  1.4 mm tall, on the part's own lattice, placed so that the identical part
  turned for the opposite face presents an open cell where each bump
  arrives.
- Plates: bumps at columns −6/+6 of row +6 and −4/+8 of row −6. The plate
  turned over for the bottom mirrors y; each bump lands two cells from any
  pad. Stack pitch 34.8 mm.
- Walls: bumps at columns −8/+4 of rows +1 and −1. The wall turned end for
  end maps column i to −i−1 on those rows; each bump lands three cells from
  any pad. Lateral pitch 112.6 mm.
- No connector part of any kind.

## Consequences

- Six part types per drive and bay, none of them a connector.
- Bumps locate and stop sliding; they do not lock. Glue them if a block
  must lift as one.
- Orientation matters: the offsets assume neighbouring plates and walls
  face the same way. (The plates' arrows were later dropped; their slots
  show front and back, see design.md.)
- Wall venting is three rows of 6 mm cells with row 0 kept clear.
- Bay stiffness comes from the tab joints plus the rear panel and the
  inserted caddy; glue is recommended for a stack that will be moved.
- Checks: a neighbour shifted 1 mm along the bay, stacked or beside, must
  hit the bumps.

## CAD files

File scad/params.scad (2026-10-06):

// Stackable 3.5" disk bay — shared parameters.
// All parts share one coordinate frame:
//   x: rear (connector face of the drive, x = 0) -> front (bezel)
//   y: width, centred on 0
//   z: 0 = underside of the caddy floor (= top of the bay floor)
// Units: mm.

$fn = $preview ? 32 : 72;

// ---------------------------------------------------------------- 3.5" drive
// SFF-8301 envelope and mounting holes, all measured from the connector end.
hdd_w = 101.6;                 // A3
hdd_l = 147.0;                 // A2 max; short drives are fine, they just sit deeper
hdd_h = 26.1;                  // A1 max; 20.2 mm drives also fit
hdd_side_hole_z = 6.35;        // A10, above the drive's bottom face
hdd_side_hole_x = [28.5, 130.1]; // A8, A8 + A9
hdd_bot_hole_x = [41.28, 85.73, 117.48]; // A7, A7 + A6, A7 + A13
hdd_bot_hole_y = 95.25/2;      // A4, centred
hdd_hole_minor_d = 2.8;        // 6-32 UNC tapped hole, thread minor diameter
hdd_hole_depth = 3.56;         // the drive takes this much fastener penetration

// ---- SATA device plug (SATA-IO internal device plug, nominal) -----------
// Shared by the drive model and the cable-plug model.
sata_pitch        = 1.27;
sata_sig_pins     = 7;
sata_pwr_pins     = 15;
sata_sig_l        = 10.4;              // signal segment
sata_key_l        = 2.4;               // gap between segments
sata_pwr_l        = 20.6;              // power segment
sata_edge_off     = 13.43;             // signal segment's outer edge (datum B) from the drive's +y
                                      // edge (datum Y): SFF-8323 A13 for 3.5", SFF-8223 A13 for 2.5",
                                      // the same on both so one backplane takes either. Viewed from
                                      // the rear, label up, that edge is on the left (checked on a
                                      // real drive); the segments run from it toward -y
sata_tongue_t     = 1.6;               // blade thickness
sata_tongue_z     = 2.6;               // blade underside above the drive's bottom
sata_tongue_depth = 6.0;               // how far the blade reaches into the pocket
sata_pocket_h     = 9.0;
sata_pocket_d     = 6.5;               // pocket depth into the drive from the connector face
sata_pocket_pad   = 1.5;               // pocket wider than the tongue each side

sata_y0  = hdd_w/2 - sata_edge_off;                        // 37.37, outer edge of the signal segment
sata_l   = sata_sig_l + sata_key_l + sata_pwr_l;           // 33.4


// ---------------------------------------------------------------- clearances
clr       = 0.3;   // drive <-> caddy, per side
slide_clr = 0.4;   // caddy <-> bay, per side

// ---------------------------------------------------------------- caddy
c_floor      = 2.0;
c_wall       = 2.4;
c_wall_h     = 25;   // wall height above the floor top (room for the diagonal fingers)
c_rear_gap   = 3;    // caddy starts here so the connector face stays clear
c_front_gap  = 0.5;  // drive front face <-> bezel
c_frame      = 6;    // solid frame around the honeycomb floor

c_in_w   = hdd_w + 2*clr;             // 102.2
c_w      = c_in_w + 2*c_wall;         // 107.0
c_body_l = hdd_l + c_front_gap;       // 147.5 — walls run 0 .. c_body_l
c_wall_top = c_floor + c_wall_h;      // 27.0
pin_z    = c_floor + hdd_side_hole_z; // 8.35
sata_z0  = c_floor + sata_tongue_z;   // tongue underside in the shared frame

// pins that engage the drive's side holes
pin_d    = 2.6;          // < 2.8 minor diameter
pin_len  = clr + 1.8;    // protrusion from the wall's inner face (1.8 mm into the hole)
pin_tip  = 1.2;          // conical tip length (cams the finger open)

// Cantilever fingers carrying the +y pins. They run at 45 degrees from the
// wall's top rim down to the pin, so every slot face is a 45-degree overhang
// and the tray prints flat with no support. A horizontal finger would float
// over its lower slot on its first layer.
finger_angle = 45;       // from horizontal; 45 is the shallowest that prints unsupported
finger_w   = 6;          // beam width, in the plane of the wall
finger_t   = 1.6;        // beam thickness (the outer face is recessed from the 2.4 wall)
finger_gap = 1.2;        // through-slot around each finger
finger_rim = 3;          // wall left above the slot's highest point (its corner at the root,
                         // which sits (finger_w/2 + finger_gap) * cos(angle) above the beam's centreline)
finger_tip_flat = 1.6;   // the beam's lowest corner is cut flat this wide: its first layer is
                         // a bead four lines wide and 1.6 mm long, not a knife edge
// [pin x, direction the root goes along x]
fingers = [ [hdd_side_hole_x[0], +1],
            [hdd_side_hole_x[1], -1] ];

// bezel. A flat plate, printed front face down, that joins the tray by
// tabs through slots, so neither part needs support. No handle: a drawer-
// style finger notch cut into the top edge, near one corner, to pull by.
bezel_t      = 2;                     // a flat plate the size of the bay's front face
bz_pull_w    = 36;                    // notch width at the top edge
bz_pull_wb   = 20;                    // and at its bottom
bz_pull_d    = 10;                    // depth down from the top edge
bz_pull_r    = 4;                     // radius in the bottom corners
bz_pull_f    = 3;                     // radius on the edge where the notch leaves the top edge
bz_tab_h     = 8;                     // wall tab height (z), centred on the finger height
bz_tab_w     = 60;                    // floor tab width (y)
bz_tab_clr   = 0.08;                  // per side across a wall tab's thickness: a friction fit
bz_floor_clr = 0.05;                  // per side across the floor tab's thickness (the long slot)
bz_end_clr   = 0.15;                  // per side along a tab's length: no grip there, room for elephant foot

// ---------------------------------------------------------------- bay
// Four flat parts: two identical plates (top/bottom), two identical walls,
// joined by tabs through slots. Every part prints flat with no supports.
b_t     = 2.4;                        // plate thickness
b_wall  = 2.4;                        // wall thickness
b_in_w  = c_w + 2*slide_clr;          // 107.8
b_in_h  = c_floor + hdd_h + 1.9;      // 30.0
b_w     = b_in_w + 2*b_wall;          // 112.6
b_h     = b_in_h + 2*b_t;             // 34.8
b_l     = c_body_l;                   // 147.5 — front face; bezel sits outside
b_x0    = -5;                         // rear face; room for the rear panel behind the drive
b_xc    = (b_x0 + b_l) / 2;           // part centre along x (patterns are symmetric about it)
b_z0    = -b_t;                       // bottom of the bay
b_z1    = b_in_h + b_t;               // top of the bay

// wall tabs through the plates
tab_len  = 14;
tab_x    = [b_xc - 54, b_xc, b_xc + 54];  // symmetric so both walls are one part
tab_clr  = 0.15;                      // per side, tab in slot
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

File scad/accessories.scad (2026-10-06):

// Accessories: the 2.5" drive adapter, feet, and joiner plates. Modules in
// the shared frame where they have a natural place (adapter in the caddy,
// foot under a bottom plate), in their own flat frame otherwise.
include <lib.scad>

// horizontal hole along y through a wall, teardrop-pointed up so it prints
// without support (the wall stands vertical on the bed)
module teardrop_y(x, z, d, y0, y1) {
    translate([x, max(y0, y1), z]) rotate([90, 0, 0]) linear_extrude(height = abs(y1 - y0)) {
        circle(d = d);
        rotate(45) square(d / 2);            // 90-degree point up
    }
}
// pin along +y (s = 1) or -y from a wall face at y0, conical tip
module side_pin(x, z, y0, s, d, len) {
    translate([x, y0 - s * 0.01, z]) rotate([s > 0 ? -90 : 90, 0, 0]) {
        cylinder(d = d, h = len - 0.8 + 0.01);
        translate([0, 0, len - 0.8]) cylinder(d1 = d, d2 = d * 0.45, h = 0.8);
    }
}

// ---- 2.5" adapter ------------------------------------------------------------
// In the caddy in place of a 3.5" drive (shared frame, z from the caddy
// floor up). The drive sits against the +y side, where its SATA connector
// is. It hangs on three pins: two on the -y rail, one on the +y strip near
// its free end. Tilt the drive onto the rail's pins, press the other side
// down: the strip flexes out and its pin snaps in. In the caddy the strip is
// backed by the caddy wall, so the drive cannot come out.
module adapter25(protrusions = true) {
    x0 = c_rear_gap;  x1 = ad_len;
    ys = hdd_w/2;     yr = -hdd_w/2;                 // strip side (+y), rail side (-y)
    z0 = c_floor;     zt = c_floor + ad_h;
    yo = yr + ad_wall;                               // outer rail's inner face
    difference() {
        union() {
            box([x0, ys, z0], [x1, ys - ad_strip_t, zt]);                 // +y strip
            box([x0, ad_in_y, z0], [h25_x1 + ad_wall, ad_in_y - ad_wall, zt]);   // -y inner rail, beside the drive
            box([x0, yo, z0], [x1, yr, zt]);                               // -y outer rail
            box([x0, ad_in_y, z0], [x1, yr, z0 + ad_base]);                // base beside the drive
            box([h25_x1, ys, z0], [x1, yr, z0 + ad_base]);                 // base in front of it
            box([h25_x1, ys, z0], [h25_x1 + ad_wall, yr, zt]);             // cross rib at the drive's front
            box([x1 - ad_wall, ys, z0], [x1, yr, zt]);                     // front end rib
            for (x = [x0, (x0 + h25_x1) / 2 - ad_wall / 2])                // ribs across the -y rail
                box([x, ad_in_y, z0], [x + ad_wall, yr, zt]);
        }
        // the caddy's pins: finger ones through the strip, fixed ones through the outer rail
        for (x = hdd_side_hole_x) {
            teardrop_y(x, pin_z, ad_hole_d, ys + 1, ys - ad_strip_t - 1);
            teardrop_y(x, pin_z, ad_hole_d, yo + 1, yr - 1);
        }
        // vents in the base, on the caddy floor's lattice (y ranges as [from, to])
        for (r = [[ad_in_y - ad_wall, yo, x0 + ad_wall, h25_x1], [ys - ad_strip_t, yo, h25_x1 + ad_wall, x1 - ad_wall]]) {
            cx = (r[2] + r[3]) / 2;  cy = (r[0] + r[1]) / 2;
            translate([cx, cy, z0 + ad_base / 2])
                honeycomb_cut([r[3] - r[2] - 3, abs(r[1] - r[0]) - 3], ad_base + 2, c_hex_cell, c_hex_web,
                              [[(x0 + h25_x1) / 2 - ad_wall / 2 - 2 - cx, -50, (x0 + h25_x1) / 2 + ad_wall / 2 + 2 - cx, 50]],
                              [b_xc - cx, -cy]);
        }
    }
    // pins into the 2.5" drive: two from the -y rail, one from the +y strip
    if (protrusions) for (x = h25_hole_x) side_pin(x, c_floor + h25_hole_z, ad_in_y, 1, ad_pin_d, ad_pin_len + ad_clr);
    if (protrusions) side_pin(h25_hole_x[0], c_floor + h25_hole_z, ys - ad_strip_t, -1, ad_pin_d, ad_pin_len + ad_clr);
}

// ---- foot --------------------------------------------------------------------
// Own frame: top face at z = 0, body below, pins up. foot_placed() puts one
// under a bottom plate at cell cluster c = [i, j].
function foot_pins() = [[-hex_dx / 2, -hex_dy / 3], [hex_dx / 2, -hex_dy / 3], [0, 2 * hex_dy / 3]];
module foot() {
    translate([0, 0, -foot_h]) linear_extrude(height = foot_h) rotate(30) circle(r = foot_af / sqrt(3), $fn = 6);
    for (p = foot_pins()) translate([p[0], p[1], 0])
        linear_extrude(height = foot_pin_h, scale = 0.93) rotate(30) circle(r = plate_bump_af / sqrt(3), $fn = 6);
}
function foot_centre(c) = let(a = plate_cell(c[0], c[1])) [a[0] + hex_dx / 2, a[1] + hex_dy / 3];
module foot_placed(c) translate([foot_centre(c)[0], foot_centre(c)[1], b_z0]) foot();

// ---- joiner plates -----------------------------------------------------------
// Own frame: u = x along the bay (b_x0 .. b_l), v across the joint from 0 to
// n half zones, w = 0 .. jn_t. fam "w" (between stacked bays, zones half a
// bay wide) or "h" (between bays side by side, zones half a bay high).
// lock_lo / lock_hi: dovetails on the v = 0 / v = top edge.
function jn_zone(fam) = fam == "w" ? jn_w_zone : jn_h_zone;
module dovetail2d(u, v, dir, grow = 0) {       // neck on v, head toward dir (+1 / -1)
    offset(delta = grow) polygon([[u - jn_dt_neck / 2, v - dir * 0.01], [u + jn_dt_neck / 2, v - dir * 0.01],
                                  [u + jn_dt_head / 2, v + dir * jn_dt_depth], [u - jn_dt_head / 2, v + dir * jn_dt_depth]]);
}
// honeycomb cells of zone k: a bay half's lattice, rows counted from the
// zone edge that lies on the bay's centre line (`from` = 0: the lower edge,
// 1: the upper edge). Whole cells only, a web from every edge and dovetail.
module jn_cells(fam, n, k, from, lock_lo, lock_hi) {
    Z = jn_zone(fam);  V = n * Z;  r = hex_cell / sqrt(3);  m = jn_edge;
    v0 = from == 0 ? k * Z : (k + 1) * Z;  sg = from == 0 ? 1 : -1;
    dts = concat(lock_hi ? [for (t = jn_dt) [b_xc + t, V], for (t = jn_dt) [b_xc - t, V]] : [],
                 lock_lo ? [for (t = jn_dt) [b_xc - t, 0], for (t = jn_dt) [b_xc + t, 0]] : []);
    for (j = [0 : ceil(Z / hex_dy)], i = [-12 : 12]) {
        u = b_xc + i * hex_dx + (j % 2 == 0 ? 0 : hex_dx / 2);
        v = v0 + sg * j * hex_dy;
        near_dt = len([for (d = dts) if (abs(u - d[0]) < jn_dt_head / 2 + hex_cell / 2 + m &&
                                         abs(v - d[1]) < jn_dt_depth + r + m) 1]) > 0;
        if (u - hex_cell / 2 >= b_x0 + m && u + hex_cell / 2 <= b_l - m &&
            v - r >= k * Z + m && v + r <= (k + 1) * Z - m && !near_dt)
            translate([u, v]) rotate(30) circle(r = r, $fn = 6);
    }
}
module joiner2d(fam, n, lock_lo = true, lock_hi = true) {
    Z = jn_zone(fam);  V = n * Z;
    difference() {
        union() {
            translate([b_x0, 0]) square([b_l - b_x0, V]);
            if (lock_hi) for (t = jn_dt) dovetail2d(b_xc + t, V, 1);        // tabs up
            if (lock_lo) for (t = jn_dt) dovetail2d(b_xc - t, 0, -1);       // tabs down, mirrored
        }
        if (lock_hi) for (t = jn_dt) dovetail2d(b_xc - t, V, -1, jn_dt_clr);   // sockets for the piece above
        if (lock_lo) for (t = jn_dt) dovetail2d(b_xc + t, 0, 1, jn_dt_clr);    // and below
        // half piece: its upper edge is a bay's centre line. Longer pieces
        // run from one bay's centre line to another's, so the zones alternate:
        // even ones count rows from their lower edge, odd ones from their upper
        if (n == 1) jn_cells(fam, 1, 0, 1, lock_lo, lock_hi);
        else for (k = [0 : n - 1]) jn_cells(fam, n, k, k % 2 == 0 ? 0 : 1, lock_lo, lock_hi);
    }
}
module joiner(fam, n, lock_lo = true, lock_hi = true) linear_extrude(height = jn_t) joiner2d(fam, n, lock_lo, lock_hi);
// the half pieces lock on their upper (centre-line) edge only; turn one round
// for the other half
module joiner_part(kind) {
    if (kind == "w1")  joiner("w", 2);
    if (kind == "w05") joiner("w", 1, lock_lo = false);
    if (kind == "h1")  joiner("h", 2);
    if (kind == "h05") joiner("h", 1, lock_lo = false);
    if (kind == "h3")  joiner("h", 6);              // three bays high
}
// placed in the shared frame: a width joiner on top of the bay at the origin,
// starting at y = y0; a height joiner on the +y face of that bay, starting
// at z = z0
module joiner_w_at(n, y0, lock_lo = true, lock_hi = true, turned = false)
    translate([0, y0, b_z1]) turn_uv(turned, n * jn_w_zone) joiner("w", n, lock_lo, lock_hi);
module joiner_h_at(n, z0, lock_lo = true, lock_hi = true, turned = false)
    translate([0, b_w / 2 + jn_t, z0]) rotate([90, 0, 0]) turn_uv(turned, n * jn_h_zone) joiner("h", n, lock_lo, lock_hi);
// in-plane half turn of a piece about its centre
module turn_uv(turned, V) {
    if (turned) translate([b_x0 + b_l, V, 0]) rotate([0, 0, 180]) children();
    else children();
}

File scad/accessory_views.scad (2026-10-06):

// Views of the accessories in use. `mode` picks the scene, `part` one class
// for a per-colour export.
include <params.scad>
use <hdd25.scad>
use <sata_plugs.scad>
use <caddy.scad>
use <bay.scad>
use <accessories.scad>

mode = "adapter";
part = "";
function on(p) = part == "" || part == p;
lift = 25;

// 2.5" drive in the adapter in the caddy, the drive lifted out
if (mode == "adapter") {
    if (on("trays"))    caddy_tray();
    if (on("adapters")) adapter25();
    if (on("hdds"))     translate([0, 0, lift]) hdd25();
}
// seated: drive in the adapter in the caddy in the bay, with the cable plugs
if (mode == "adapter_seated") {
    if (on("bays"))     bay(top = false);
    if (on("trays"))    caddy_tray(spring_defl = sp_preload);
    if (on("adapters")) adapter25();
    if (on("hdds"))     hdd25();
    if (on("plugs"))    sata_plugs(h25_dy);
}
// four feet under a bay, lowered away
if (mode == "feet") {
    if (on("bays"))  bay();
    if (on("feet"))  for (c = foot_cells) translate([0, 0, -lift]) foot_placed(c);
}
// two layers of two bays with a 0.5 + 1 + 0.5 width joiner between them,
// exploded upward
if (mode == "joiners_w") {
    for (i = [0, 1]) translate([0, i * pitch_y, 0]) {
        if (on("bays")) bay();
        if (on("bays2")) translate([0, 0, pitch_z + jn_t + 2 * lift]) bay();
    }
    translate([0, 0, lift]) {
        if (on("j05")) joiner_w_at(1, -b_w / 2, lock_lo = false);
        if (on("j1"))  joiner_w_at(2, 0);
        if (on("j05")) joiner_w_at(1, b_w, lock_lo = false, turned = true);
    }
}

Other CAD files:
scad/adapter25.scad
scad/assembled.scad
scad/assembly.scad
scad/bay.scad
scad/bezel.scad
scad/caddy.scad
scad/caddy_tray.scad
scad/checks.scad
scad/coupon.scad
scad/foot.scad
scad/hdd.scad
scad/hdd25.scad
scad/joiner.scad
scad/joining.scad
scad/lib.scad
scad/plate.scad
scad/rear.scad
scad/sata_plugs.scad
scad/steps.scad
scad/testfit.scad
scad/thin.scad
scad/vent.scad
scad/wall.scad

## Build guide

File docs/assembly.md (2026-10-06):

# Assembly

One bay and one caddy per drive. Every part prints flat with no support; see
the parts table in the [README](../README.md). Glue is never required: the
tabs are friction fits. A drop of glue on the bay's tabs makes it permanent.

Colours in the pictures: plates blue, walls green, rear panel purple, caddy
tray orange, bezel brown, drive grey.

## Bay

### 1. Walls onto the rear panel

Hold the panel with its low groove on the outside and the open corner at
the bottom, on the same side as the drive's SATA connector: on the left,
seen from behind. Slide each wall
sideways onto the panel's side tab, low groove on the outside and near the
floor. Either end of a wall may face the rear. Panel and walls now stand
as a U.

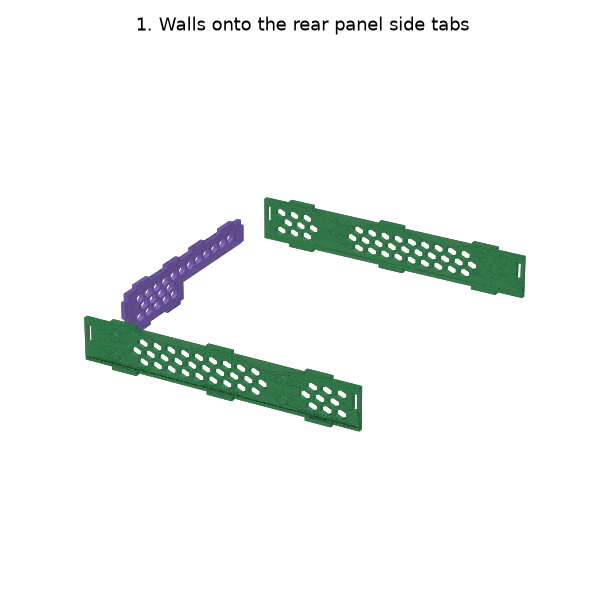
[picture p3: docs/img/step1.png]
Walls sliding onto the rear panel's side tabs


### 2. Into the bottom plate

Take the plate with **two** slots, bumps down, slots at the rear. Lower
the U onto it: the walls' three bottom tabs and the panel's two bottom tabs
all drop into their slots together.

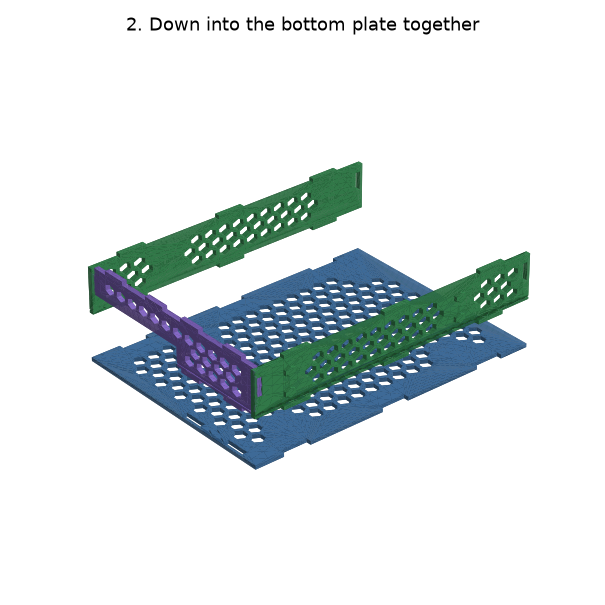
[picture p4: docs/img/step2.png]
Panel and walls going down into the bottom plate


### 3. Top plate on

Take the plate with **six** slots, bumps up, the row of four at the rear.
Drop it over the walls' top tabs and the panel's four top tabs. It caps
the panel's side edges.

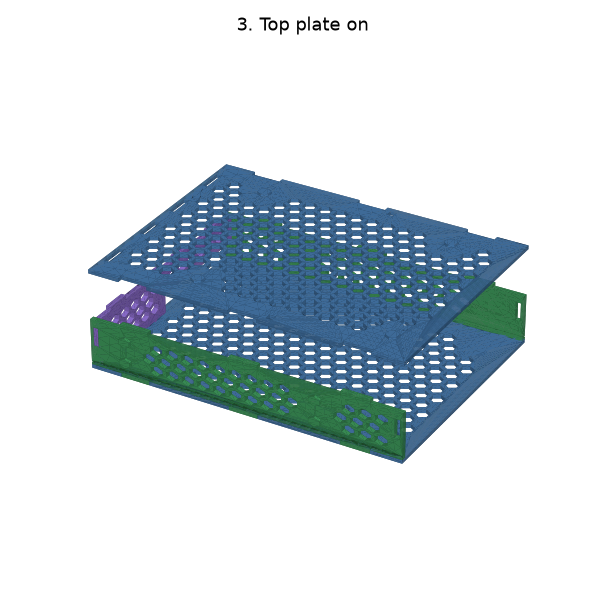
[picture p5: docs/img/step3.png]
Top plate going on


## Caddy

### 4. Bezel onto the tray

Press the bezel onto the tray's three front tabs, one on each wall and the
long one on the floor, with the finger notch at the top.

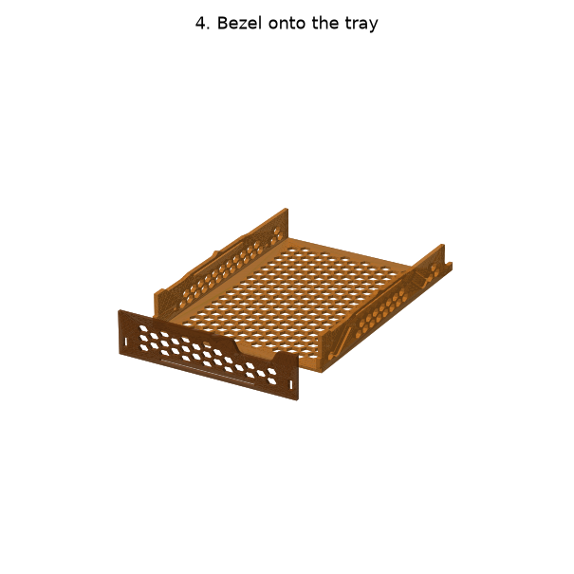
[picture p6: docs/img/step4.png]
Bezel pressing onto the tray


### 5. Drive into the caddy

Connector end to the rear. Tilt the drive onto the two fixed pins on the
wall without fingers, its front corner under the bezel's lip, then press
the other edge down: the two fingers flex out and their pins snap into the
drive's side holes, and the bezel gives a little as the drive passes under
the lip.

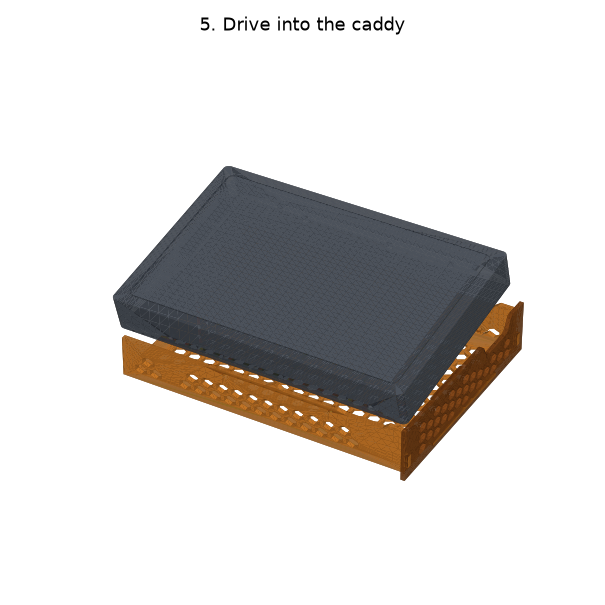
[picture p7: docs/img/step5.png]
Drive going into the caddy


To take a drive out, put a small flat screwdriver into the hex hole at the
low end of each finger, against the finger's tip, and pry the tip outward
until its pin leaves the drive's hole. Then lift that edge of the drive.

## Into the bay

### 6. Slide the caddy in

Rear first. The spring bumps on top of the caddy walls ride under the top
plate and click into its two small slots as the bezel meets the bay.

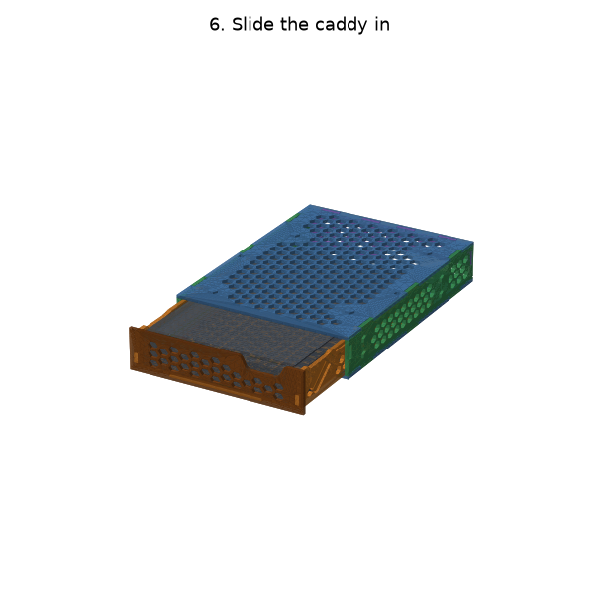
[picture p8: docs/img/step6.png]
Caddy sliding into the bay


### 7. Seated, and how to get it out

Seated, the springs hold the caddy down and the bezel tight against the
bay. To remove it, pull by the notch in the bezel's top edge, or push the
tab that sticks out of the rear panel's open corner from behind.

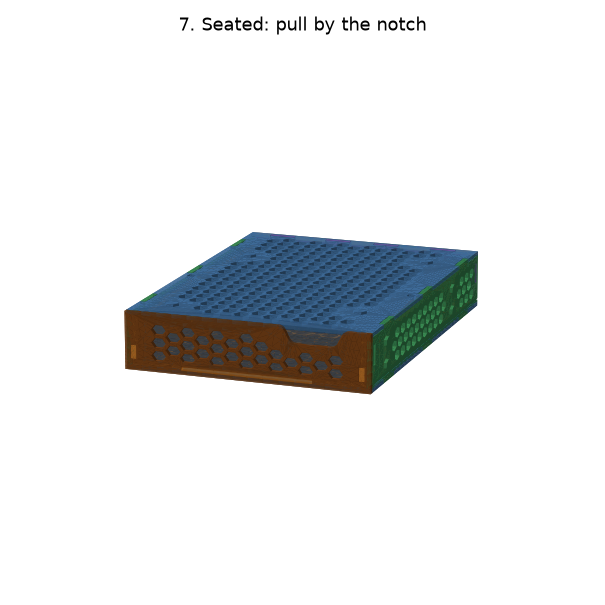
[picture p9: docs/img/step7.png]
Seated caddy, with the finger notch in the bezel's top edge


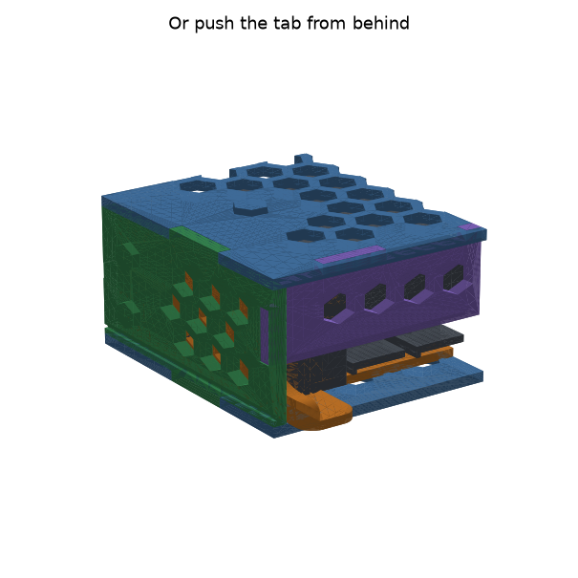
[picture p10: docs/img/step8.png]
The rear corner close up: the push tab under the drive's connector, in the rear panel's open corner


## Joining bays

Set the next bay on top, or bring it in from the side, facing the same way.
The bumps drop into the neighbour's honeycomb cells; no extra parts. Bumps
locate, they do not lock: glue them if a block must lift as one.

## Accessories

### 2.5" drive in an adapter

The adapter takes the place of a 3.5" drive in an ordinary caddy. Hang the
2.5" drive on the two pins of the adapter's long rail, connector end to the
rear, then press its other side down until the thin strip's pin snaps into
the drive's side hole. Put the adapter into the caddy like a 3.5" drive:
the rail side onto the fixed pins first, then press the strip side down
past the fingers. The drive's SATA connector comes out of the rear panel's
open corner where a 3.5" drive's would.

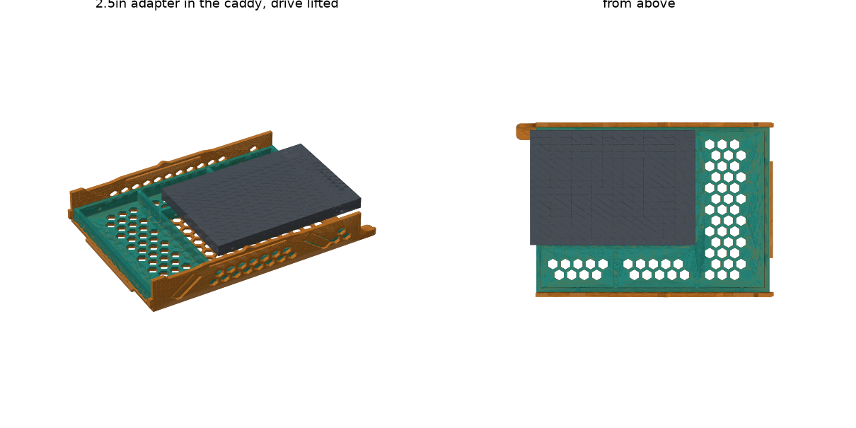
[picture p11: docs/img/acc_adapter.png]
2.5" adapter in the caddy, drive lifted


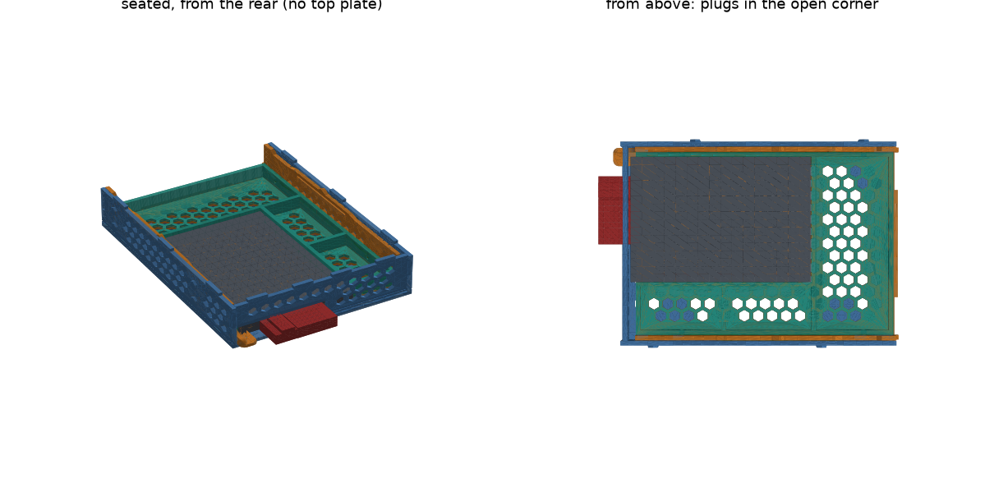
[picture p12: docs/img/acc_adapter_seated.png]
Seated in a bay, top plate off: the plugs pass the open corner


### Feet

Press four feet into the bottom plate of the lowest bays, near the
corners. Each foot's three pins go into three neighbouring open cells: two
in one row, one in the next row between them.

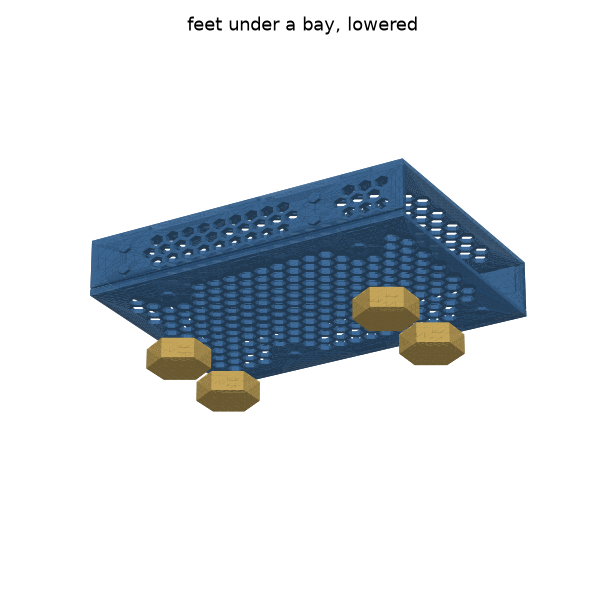
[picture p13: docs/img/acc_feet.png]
Feet under a bay


### Joiner plates

Lay a joiner on a bay's top plate, or against its side wall, and set the
next bay on it, facing the same way. The bumps of both bays drop into the
joiner's holes. Slide pieces together along their dovetails before laying
them. Over two columns or rows, use 0.5 + 1 + 0.5, so the seams fall at
mid-bay and tie the bays together; on a single bay, use 0.5 + 0.5, the
second half turned round. For four rows side by side, 0.5 + 3 + 0.5.
Use joiners in one direction per block: between
layers, with the columns touching, or between columns, with the layers
touching.

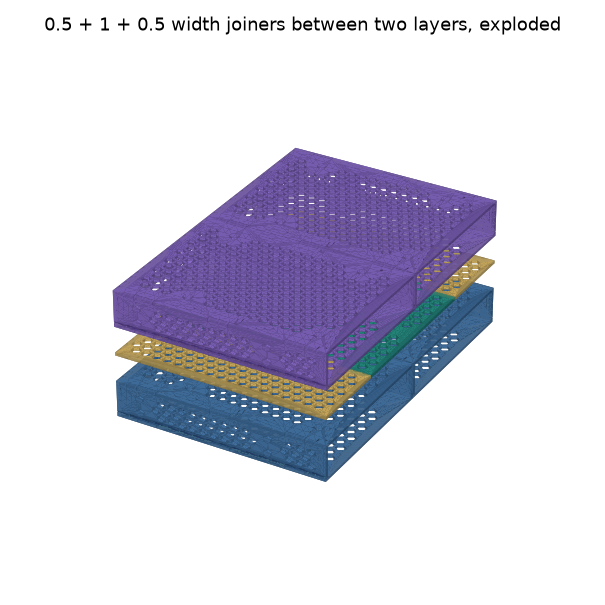
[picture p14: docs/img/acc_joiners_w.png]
Width joiners, 0.5 + 1 + 0.5, between two layers of two bays


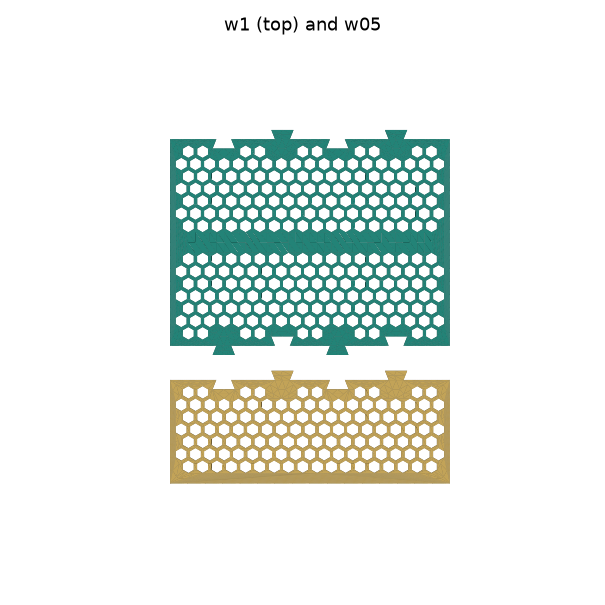
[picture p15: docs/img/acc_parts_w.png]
Width joiner pieces, 1 and 0.5


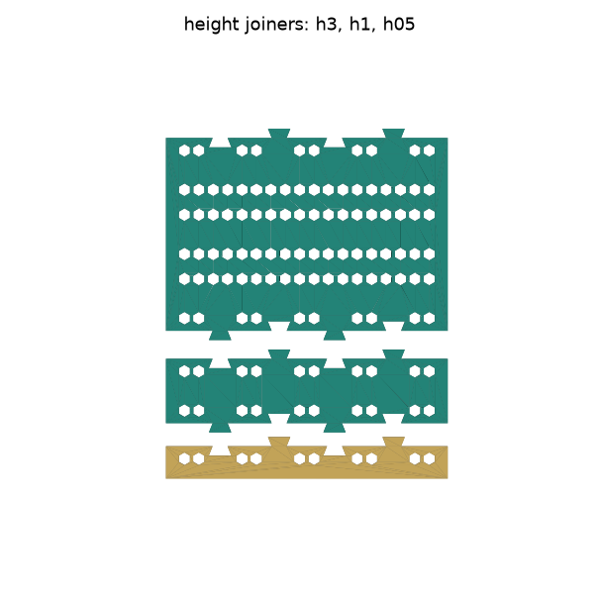
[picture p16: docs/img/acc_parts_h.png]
Height joiner pieces, 3, 1 and 0.5


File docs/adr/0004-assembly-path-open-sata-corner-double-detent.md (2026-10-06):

# 0004 — A provable assembly path, an open SATA corner, two detent bumps

> **Partly superseded by [0005](0005-top-edge-spring-lock-grooved-rear-panel.md)**
> after the first print. The detent finger and the lifted-wall assembly path
> are replaced; the open SATA corner stands.
>
> **Mirrored by [0010](0010-sata-connector-on-the-plus-y-side.md):** the
> open corner is the +y one and the bottom plate tabs sit on the −y half
> (−40 and −12 mm). Read −y for +y and back below.

## Context

Three problems the model has to rule out. A closed SATA window in the rear
panel leaves a 0.5 mm strip under it and a 1.7 mm strip beside it, weaker
than no material. A single detent bump on the caddy clicks into every
honeycomb cell it crosses on the way in. And with closed slots everywhere,
the bay cannot be assembled: a wall would have to move sideways onto the
panel's tab and downward into the plate at the same time.

## Decision

- The rear panel's lower −y corner is cut away from the bottom edge and the
  side edge up to 12.5 mm. The wall tab sits at 13 to 25 mm, the plate
  tabs on the +y half (12 and 40 mm), and the plate carries both mirror
  images of the slots so it stays one part.
- The detent finger carries two bumps a lattice pitch apart along its 45°
  beam (7.8 mm in x, 7.8 mm in z); the bay wall has a hole for each. One
  bump is on a web whenever the other is over a cell.
- Assembly order is fixed as: panel into the bottom plate; walls slid in
  from the sides, lifted one plate thickness, then dropped; top plate on.
  The wall's panel slot extends one plate thickness below the tab so the
  lifted wall can take the tab sideways. Six checks sweep that path.

## Consequences

- The panel is an L; its stiffness comes from the full-height +y half and
  the top strip, which is what the plugs leave room for anyway.
- Two unused slots in each plate, 2.4 × 12.3 mm, a little more venting.
- The tab sits at the top of a slot 2.4 mm taller than itself; the plate
  tabs fix the wall's height, so the slack is harmless.

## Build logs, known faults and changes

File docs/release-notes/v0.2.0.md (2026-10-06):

# 0.2.0

The second iteration of the stackable 3.5" disk bay. It fixes what the first
test print and a drive test fit found, puts the SATA connector on the correct
side, and adds a 2.5" adapter, feet and joiner plates.

**Reprint everything.** Parts from 0.1.0 do not mix with 0.2.0: the rear panel,
bottom plate, walls, caddy tray and bezel have all changed.

## Fixes from the first print and test fit

- **SATA connector on the correct side.** The model had the connector
  mirrored. Seen from behind with the label up, it is at the left, as on a real
  drive. The rear panel's open corner, the bottom plate's rear-panel slots, the
  caddy's push tab and the 2.5" adapter all moved with it.
  ([ADR 0010](https://github.com/kisst/stackable-disk-bay/blob/v0.2.0/docs/adr/0010-sata-connector-on-the-plus-y-side.md))
- **The caddy now locks into the bay.** The side detent never clicked. It is
  replaced by a leaf spring on the top edge of each caddy wall, which clicks
  into a slot in the top plate and keeps the caddy pressed down and the bezel
  tight against the bay.
  ([ADR 0005](https://github.com/kisst/stackable-disk-bay/blob/v0.2.0/docs/adr/0005-top-edge-spring-lock-grooved-rear-panel.md))
- **Drives can be taken out again.** Once its pins were in, a drive was almost
  impossible to remove. A service hole next to each finger tip, part of the
  honeycomb pattern, lets a small screwdriver pry the pin out.
  ([ADR 0012](https://github.com/kisst/stackable-disk-bay/blob/v0.2.0/docs/adr/0012-finger-service-holes.md))
- **The rear panel no longer rattles.** The walls now slide onto the panel's
  side tabs first, so each slot fits its tab exactly.
  ([ADR 0009](https://github.com/kisst/stackable-disk-bay/blob/v0.2.0/docs/adr/0009-rear-panel-side-tabs-walls-first.md))
- **Tighter press fits.** The bezel tabs and rear panel tabs are 0.08 mm a side
  (0.05 mm across the bezel's floor tab), so they hold without glue.
- **The top plate is propped at the front.** A short lip on the bezel holds up
  the middle of the top plate, and the caddy walls rise almost to the plate at
  the bezel end to hold up its edges. Both stop 0.2 mm short, so they cannot
  bind.
  ([ADR 0011](https://github.com/kisst/stackable-disk-bay/blob/v0.2.0/docs/adr/0011-bezel-lip-props-the-top-plate.md))

## New

- **Push tab.** The caddy tray reaches through the rear panel's open corner,
  so a caddy can be pushed out from behind.
  ([ADR 0007](https://github.com/kisst/stackable-disk-bay/blob/v0.2.0/docs/adr/0007-caddy-push-tab-through-sata-corner.md))
- **Finger notch instead of a handle.** The bezel is now a flat plate with a
  drawer-style notch to pull by, and prints with no support.
  ([ADR 0006](https://github.com/kisst/stackable-disk-bay/blob/v0.2.0/docs/adr/0006-bezel-finger-notch-instead-of-handle.md))
- **2.5" adapter.** A 2.5" HDD or SSD (5 to 15 mm) goes into a normal caddy
  in place of a 3.5" drive, with its connector where a 3.5" drive's would be.
- **Feet** lift the bottom bay off the surface for airflow. Each locks into
  three honeycomb cells.
- **Joiner plates**, in full and half sizes, go between stacked bays or bays
  side by side. They interlock with dovetails, so joints run brick-style
  across bays. ([ADR 0008](https://github.com/kisst/stackable-disk-bay/blob/v0.2.0/docs/adr/0008-accessories-adapter-feet-joiners.md))
- **Assembly guide** with pictures for every step:
  [docs/assembly.md](https://github.com/kisst/stackable-disk-bay/blob/v0.2.0/docs/assembly.md).

## Release assets

Printable parts, as STL:

| File | Print |
| --- | --- |
| `caddy_tray.stl`, `bezel.stl` | one each per caddy |
| `plate_top.stl`, `plate_bottom.stl` | one each per bay |
| `wall.stl` | two per bay (left and right are the same part) |
| `rear.stl` | one per bay |
| `adapter25.stl` | optional, one per 2.5" drive |
| `foot.stl` | optional, four under the bottom bay |
| `joiner_w1.stl`, `joiner_w05.stl`, `joiner_h1.stl`, `joiner_h05.stl`, `joiner_h3.stl` | optional, between bays |
| `coupon.stl` | test piece: one pin and one finger, to try against a drive first |

New in this release, coloured 3MF assemblies for checking fit in a slicer or
viewer, one object per part:

| File | Contents |
| --- | --- |
| `assembled_hdd35.3mf` | bay, caddy and 3.5" drive |
| `assembled_hdd25.3mf` | bay, caddy, 2.5" adapter and 2.5" drive |
| `bay.3mf` | the bay alone |
| `caddy_hdd35.3mf` | caddy with a 3.5" drive |
| `caddy_hdd25.3mf` | caddy with the 2.5" adapter and drive |

## Known open points

Not yet confirmed on a print:

- whether a drive goes in under the bezel's lip with the bezel already fitted,
  by flexing the bezel
- the moved rear panel opening against real SATA plugs
- the spring lock's click and release force, and whether its 54 mm slit
  bridges cleanly
- whether the new press fits push home by hand

See [What the next print has to answer](https://github.com/kisst/stackable-disk-bay/blob/v0.2.0/docs/design.md#what-the-next-print-has-to-answer).

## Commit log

2026-10-05 Add stackable disk bay model, verification scripts and docs
    [assembly.scad, bay.scad, bezel.scad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]
2026-10-05 Fail geometry checks on OpenSCAD errors instead of reading them as empty
    [checks.scad]
2026-10-06 Release 0.2.0: fixes from the first print and test fit, accessories
    - SATA connector on the +y side, as on a real drive; the rear panel's open
    corner, the bottom plate's rear slots, the push tab and the 2.5" adapter
    follow it (ADR 0010)
    - Top-edge spring lock replaces the side detent (ADR 0005); rear panel side
    tabs with walls fitted first (ADR 0009); tighter press fits
    - Service holes at the finger tips so a seated drive can be pried out
    (ADR 0012)
    - Bezel lip and raised wall front ends prop the top plate, 0.2 mm under it
    (ADR 0011)
    - Push tab, bezel finger notch, 2.5" adapter, feet and joiner plates
    (ADR 0006 to 0008); reference drive models with every mounting hole
    - Assembly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
    [accessories.scad, accessory_views.scad, adapter25.scad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]
2026-10-13 Release 0.3.0: dovetailed wall joint, pull ledge, bezel held at four corners
    - Wall tabs are dovetails in edge notches: a steep 15° flare stops a wall
    lifting off a plate, a shallow 4° splay snaps it in sideways; walls go in
    last (ADR 0014)
    - Push tab moved near the middle of the rear edge; a pull ledge with a grip
    slot and a barb that locks the bezel replaces the finger notch; firmer
    spring lock; 10 mm bezel lip (ADR 0013)
    - Two bezel tabs on each caddy wall, their outer faces sloped 4° so the
    bezel snaps on and is locked at four corners; more caddy wall vents
    (ADR 0015)
    - Lock checks demand overlap volume and fail with their angle at 0; check.sh
    and thin.sh fail on undefin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
2026-11-02 Release 0.4.0: lighter wall splay, softer spring lock, corner reliefs
    - Wall dovetail splay 4° -> 1.5° (snap 0.06 mm a tab end), flare stays at
    15°; spring lock bump 1.25 mm into the top plate, slit 1.85 mm (ADR 0016)
    - 0.5 mm corner reliefs at the wall joint: T-bones in the plates' notches
    and at the wall tab roots, turned into the dovetail ends under the
    caddy lock track; centred ones on the joiners' dovetails (ADR 0017)
    - Glue holes at two diagonal corners of the walls' rear-panel slots and
    the bezel's upper wall-tab slots, for a drop of superglue
    - assemblies.sh renders only the named assemblies' parts, once each, in
    parallel; color_mesh.py writes 3MF only unless --stl
    - Rel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
